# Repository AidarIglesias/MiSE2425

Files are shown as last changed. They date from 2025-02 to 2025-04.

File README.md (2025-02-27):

# MiSE2425
This repository is intended to work as a tracking tool for the project in the subject of Microcontollers and Embedded Systems at the University of Barcelona.

The project comprises of four main stages, listed as follows:

1. Resource Planning
2. Hardware Design
    1. Schematic Drawing
        1. Component distribution
        2. Wiring
        3. Labeling
        4. Annotating
        5. ERC Check
    2. PCB Layout
        1. Set design rules
        2. Import components from Schematic
        3. Placement
            1. Microcontroller
            2. RF sensitive components
            3. Power supply
            4. The rest
        4. Routing
            1. RF & High speed lines
            2. Differential pair lines
            3. Power lines
            4. The rest
        5. Copper pouring
    3. PCB Assembly & Soldering
3. Software Design
    1. Creating the workspace
    2. Importing libraries
    3. Creating sub-files
    4. Coding
    5. Building
    6. Test runs
    7. Optimizing the code
    8. Reparsing
    9. Decorating
4. Project Presentation

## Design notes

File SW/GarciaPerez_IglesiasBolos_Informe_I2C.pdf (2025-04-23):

# Desenvolupament del software del robot

## Enginyeria Electrònica de Telecomunicació Microcontroladors i Sistemes Empotrats Curs 2024/2025

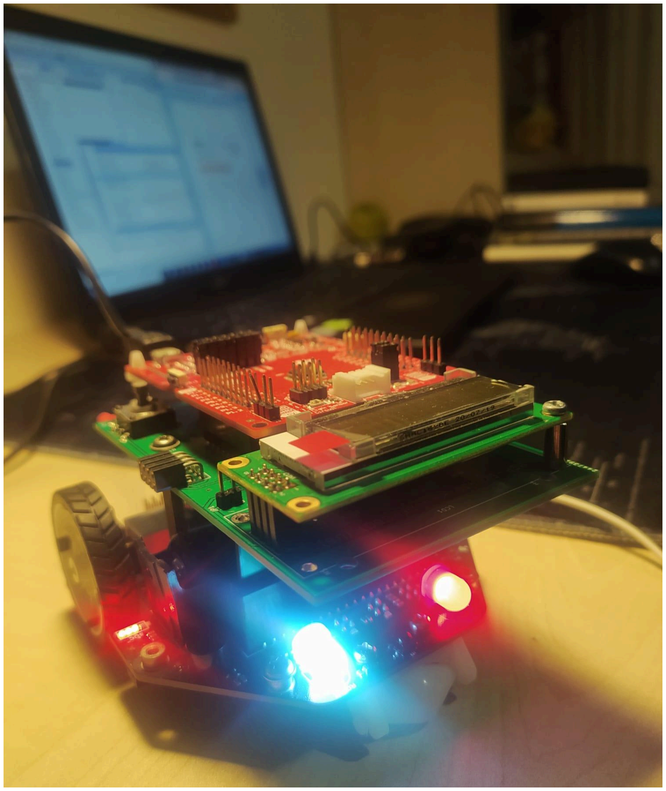
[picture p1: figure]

Aidar Iglesias | David García

Grau d'Enginyeria Electrònica de Telecomunicacions Microcontroladors i Sistemes Empotrats Curs 2024-2025
Informe desenvolupament del software del robot | Aidar Iglesias/David García Pérez

## ÍNDEX

Curs 2024-2025
Informe desenvolupament del software del robot | Aidar Iglesias/David García Pérez

## MOTIVACIÓ I OBJECTIUS

En aquest projecte, s’ha implementat un conjunt de funcionalitats a fi de controlar diferents perifèrics com LEDs RGB, motors, una pantalla LCD i un seguidor de línia, tots interconnectats mitjançant el protocol de comunicació I2C. L’objectiu principal ha estat programar aquest sistema per tal que pugui executar tasques senzilles, mitjançant interrupcions, temporitzadors i rutines d'espera.

Els diferents objectius particulars d’aquest informe son:

- Desenvolupar el software de manera escalada, mitjançant diferents fitxers C i generar els fitxers de capçalera.
- Crear una funció d’espera per controlar els retards que es troben dins del codi.
- Controlar diferents perifèrics mitjançant I2C. Entre ells, controlar els LEDs del robot, els actuadors de les rodes, la pantalla LCD i el seguidor de línia

## ESTRUCTURA GENERAL DEL SOFTWARE

El software del projecte s'organitza de manera modular per facilitar la llegibilitat, la reutilització i el manteniment del codi. Cada funcionalitat del robot relacionada amb la comunicació I2C o amb l’ús dels perifèrics digitals del microcontrolador es desenvolupa en fitxers de tipus C independents, acompanyats dels seus corresponents fitxers de capçalera, que defineixen les funcions globals accessibles des del programa main.

Aquesta modalitat permet encapsular les funcionalitats específiques com el control dels LEDs RGB, la gestió dels motors, la comunicació amb el display LCD o la configuració de rellotges i temporitzadors de manera individual.

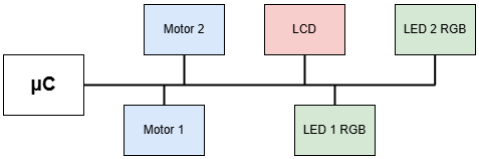
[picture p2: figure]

Figura 1: Visualització de diagrama I2C amb els diferents perifèrics.

Curs 2024-2025
Informe desenvolupament del software del robot | Aidar Iglesias/David García Pérez

## RECURSOS DE HARDWARE

Els models comercials que s’implementaran, juntament amb els seus corresponents Datasheets, es presenten a la Taula 1. A la Taula 2, es proporciona una breu descripció de cadascun.

Bloc | Recurs comercial | datasheet
Microcontrolador | MSP430FR2355TPT | MSP430FR2355TPT (https://www.ti.com/lit/ds/symlink/msp430fr2355.pdf?ts=1742411933840)
Robot | DFRobot Mcqueen Plus | DFRobot Mcqueen Plus (https://dfimg.dfrobot.com/nobody/wiki/9452afa67059f576c85b345bd385a060.pdf)
LCD | MD21605B6W-FPTLW3 | MD21605B6W-FPTLW3 (https://docs.rs-online.com/4d70/A700000009250608.pdf)
Ultrasons | URM10 | SEN0307 URM09 (https://wiki.dfrobot.com/URM09_Ultrasonic_Sensor_(Gravity_Analog)_SKU_SEN0307)
Oscil·lador | LFXTAL002997BULK | LFXTAL002997BULK (https://www.mouser.es/datasheet/2/741/LFXTAL002997Bulk-940265.pdf)
Joystick | THB001P | THB001P (https://www.ckswitches.com/media/2873/thb.pdf)
LDRs | NSL-19M51 | NSL-19M51 (https://eu.mouser.com/datasheet/2/1418/DS_NSL_19M51-2935293.pdf)
Mòdul wifi | ESP01 | ESP01 (https://docs.ai-thinker.com/_media/esp8266/docs/esp-01_product_specification_en.pdf)
Lògica joystick | LMV324 | LMV324 (https://www.ti.com/lit/ds/symlink/lmv324.pdf?ts=1742439205418)

Taula 1: Visualització dels recursos amb els respectius datasheets.

Recurs comercial | Característiques
MSP430FR2355TPT | Baix consum, memòria FRAM ràpida i múltiples protocols de comunicació
DFRobot Mcqueen Plus | Robot amb múltiples motors, sensors i funcionalitats.
MD21605B6W-FPTLW3 | Interfaç I2C senzilla, baix consum, més econòmic que una pantalla LED.
URM10 | Sensor d’alta precisió, però és més car que altres mòduls d’ultrasons.
LFXTAL002997BULK | Bona estabilitat, però requereix condensadors de càrrega per funcionar correctament.
THB001P | Joystick analògic amb un control precís dels dos eixos i un polsador integrat.
NSL-19M51 | Té una resposta no lineal que depèn molt de la il·luminació ambiental.
ESP01 | Aquest model concret de mòdul wifi té un baix cost, ocupa poca àrea i és programable amb altres entorns com arduino.
LMV324 | Operacional LM324 amb baix consum.

Taula 2: Visualització dels recursos amb una descripció.

Curs 2024-2025
Informe desenvolupament del software del robot | Aidar Iglesias/David García Pérez

## TAULA AMB PINS DEL µC

Per poder desenvolupar el software i saber quins pins s’han d’inicialitzar com a GPIOs així com tenir una idea de quins pins s’associen a cada funció del robot, s’ha adjuntat la taula amb les connexions del microcontrolador, indicant el nom del pin, el mòdul que es connecta a aquests pins i una petita descripció de la seva funció, especificant si es tracta d’una entrada o una sortida digital, una línia de comunicació (I2C, UART), una entrada analògica o un senyal específic.

Pin µC | Etiqueta | Component | Port/Pin amb funcionalitats | Descripció
2 ACLK | TP | Conn pinheader | P1.1/UCB0CLK/ACLK/OA0O/COMP0.1/A1 | Output. Test point del ACLK
3 SMCLK | TP | Conn_pinheader | P1.0/UCB0STE/SMCLK/COMP0.0/A0/Veref+ | Output. Test point del SMCLK
4 SBW | TCK | Spy By Wide | TEST/SBWTCK | I/O Pin de dades del SPW
5 SBW | TDIO | Spy By Wide | RST/NMI/SBWTDIO | I/O Pin de rellotge del Spy By Wire
6 | VCC | VCC | DVCC | Alimentació VCC
7 | GND | GND | DVSS | Gnd, punt de referència
8 XT1 | IN | CRISTALL | P2.7/TB0CLK/XIN | Input. Pin 1 del cristall
9 XT1 | OUT | CRISTALL | P2.6/MCLK/XOUT | Input. Pin 2 del cristall
12 I2C | SCL | LCD | P4.7/UCB1SOMI/UCB1SCL | SCL del I2C para conn.robot y LCD
13 I2C | SDA | LCD | P4.6/UCB1SIMO/UCB1SDA | SDA del I2C para conn. robot y LCD
14 RST | LCD | LCD | P4.5/UCB1CLK | Reset del LCD
20 | P0 | CONN_ROBOT | P6.2/TB3.3 | I/O. Pin digital per connexió robot
21 | P1 | CONN_ROBOT | P6.1/TB3.2 | I/O Pin digital per connexió robot
22 | P2 | CONN_ROBOT | P6.0/TB3.1 | I/O Pin digital per connexió robot
27 | P8 | CONN_ROBOT | P2.3/TB1TRG | I/O Pin digital per connexió robot
31 RX | ESP | MÒDUL WIFI | P1.7/UCA0TXD/UCA0SIMO/TB0.2/TDO/OA1 +/A7/VREF+ | Input. Connexió de recepció del mòdul wifi tipus UART.
32 TX | ESP | MÒDUL WIFI | P1.6/UCA0RXD/UCA0SOMI/TB0.1/TDI/TCL K/OA1-/A6 | Output. Connexió transmissió del mòdul wifi tipus UART.
37 JTK | R | joystick | P3.5/OA3O | Output. Pin digital del port 3 del joystick que determina direcció dreta (right).
38 JTK | F | joystick | P3.4/SMCLK | Output. Pin digital del port 3 del joystick que determina direcció endavant (forward)
42 LDR | R | LDR | P5.1/TB2.2/MFM.TX/A9 | Pin analògic del port 5 per LDR dret (right)
43 LDR | L | LDR | P5.0/TB2.1/MFM.RX/A8 | Pin analògic del port 5 per LDR esquerra (left)
44 JTK | SEL | joystick | P3.3/OA2+ | Ouput. Pin digital del pulsador del joystick per seleccionar al LCD.
45 JTK | B | joystick | P3.2/OA2- | Output. Pin digital del port 3 del joystick que determina direcció abaix (backward).
46 JTK | L | joystick | P3.1/OA2O | Output. Pin digital del port 3 del joystick que determina direcció esquerra (left).

Taula 3: Taula amb els diversos components de la placa i els pins corresponents del microcontrolador.

Curs 2024-2025
Informe desenvolupament del software del robot | Aidar Iglesias/David García Pérez

## DESCRIPCIÓ DE FUNCIONS DEL ROBOT

Com anteriorment s’ha esmentat, el robot integra diferents funcionalitats, proporcionades pels diferents perifèrics. Aquestes són controlades per una placa de desenvolupament MSP-EXP430FR2355, la qual té com a microcontrolador principal el MSP430FR2355 de Texas Instruments.

El desenvolupament de l’entorn de software del robot inclou funcions per al control de temporitzadors mitjançant l’ús de rellotges i funcions per al control de perifèrics, tals com LEDs RGB, actuadors i un display LCD.

El control dels LEDs RGB es realitza via protocol de comunicació I2C. S’han definit funcions per al control de l’encesa i l’apagada dels esmentats, així com per al color.

A més, el robot també té la capacitat de desplaçar-se en totes les direccions del pla sobre el qual reposa gràcies a un conjunt de dos actuadors programables per usuari. Per a aquest perifèric s’han desenvolupat un seguit de funcions que permeten el control del moviment del robot en diverses direccions. La comunicació entre la placa i el controlador dels actuadors també es fa a través d’I2C.

Addicionalment, el robot està dotat d’una petita pantalla de tipus LCD de dues línies de 16 caràcters per línia, també controlada mitjançant el protocol I2C. En el projecte s’ha creat funcions per a la representació de caràcters a través de la pantalla LCD.

Per la mateixa naturalesa del protocol de comunicació, per a cadascun dels mòduls de software que implementen el control de cadascun dels perifèrics s’ha establert un format de trama específic que inclou l’adreça del perifèric a controlar, el conjunt de dades a enviar i la longitud de la trama.

Cal destacar que totes les funcions esmentades anteriorment tenen la seva contrapart d’inicialització, que és necessària per al correcte funcionament dels perifèrics del nostre robot i, en general, per a qualsevol sistema encastat.

Curs 2024-2025
Informe desenvolupament del software del robot | Aidar Iglesias/David García Pérez

## Rellotges

En aquest projecte s’han utilitzat dues fonts de rellotge: una de 16 MHz proporcionada pel DCO (Digitally Controlled Oscillator) i una altra de 32 kHz generada pel cristall extern XT1. A través dels pins de sortida configurats al LaunchPad, s’han pogut visualitzar amb l’oscil·loscopi els dos senyals corresponents. A les Figures 2 i 3, respectivament, s’observa clarament que el senyal de 16 MHz presenta una forma d’ona més distorsionada en comparació amb la de 32 kHz. Aquesta distorsió és causada per diversos factors, com ara el soroll introduït per l’elevada freqüència, la capacitat paràsita del circuit, o limitacions de la instrumentació utilitzada. En canvi, el senyal de 32 kHz es mostra molt més estable i net, ja que treballa a una freqüència inferior i prové d’un oscil·lador més estable com és el cristall.

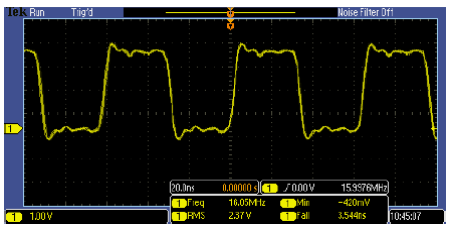
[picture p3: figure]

Figura 2: Visualització de la font de rellotge de 16 MHz.

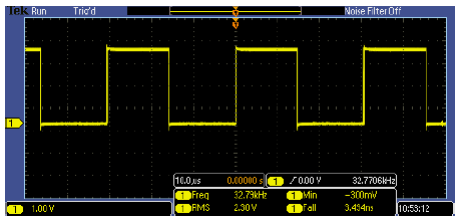
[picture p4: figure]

Figura 3: Visualització de la font de rellotge de 32 kHz.

Curs 2024-2025
Informe desenvolupament del software del robot | Aidar Iglesias/David García Pérez

### Funció delay_ms()

Per implementar retards precisos al sistema, s’ha desenvolupat la funció | delay_ms(), que permet
generar una espera en mil·lisegons. Aquesta funció inicialitza un comptador global | count_ms | i
utilitza el Timer B3 del microcontrolador per incrementar aquest valor mitjançant una interrupció generada cada 1 ms. Quan es crida la funció, s'entra en un bucle d’espera que no finalitza fins que el comptador arriba al valor indicat. L'increment del comptador es produeix a través de la subrutina d’interrupció TimerB0_ISR(). A la Figura 4 es pot observar el diagrama de flux corresponent al funcionament de la funció delay_ms(). A la Figura 5 es pot visualitzar el pols generat per un GPIO configurat com a sortida amb període de 200 ms (retard de 100 ms entre commutacions).

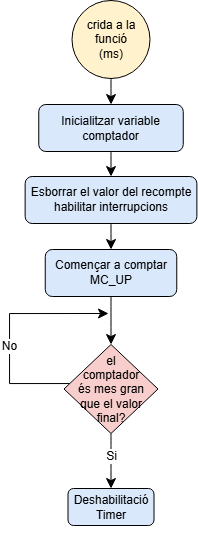
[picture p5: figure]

Figura 4: Diagrama de flux de la funció delay.

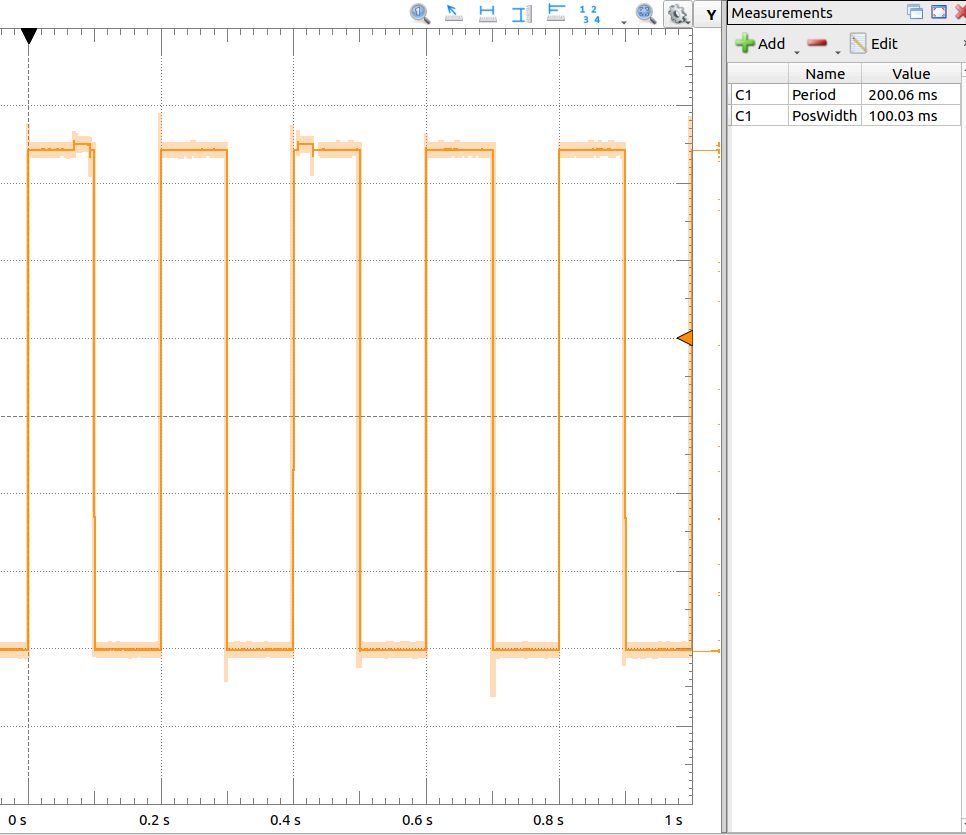
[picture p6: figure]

Figura 5: Visualització del retard generat per la funció delay amb l’oscil·loscopi. S’aprecia a la finestra de mesures que el període d’espera és de 100 ms.

## Timers

Per tal de generar temporitzacions precises en el sistema, s'ha utilitzat el mòdul TimerB3 del microcontrolador. A la funció init_TimerB(), es configura aquest temporitzador amb el rellotge SMCLK com a font, funcionant a 16 MHz. S'estableix un valor de recompte de 16000 cicles, que equival a un període d’1 mil·lisegon (tenint en compte que 1 cicle = 1/16 MHz). Aquest temporitzador s’utilitza principalment com a base per a la funció delay_ms(), la qual permet generar retards amb precisió en mil·lisegons.

Curs 2024-2025
Informe desenvolupament del software del robot | Aidar Iglesias/David García Pérez

## LEDs RGB

Els LEDs frontals del robot es controlen mitjançant trames enviades a través de l’I2C. Cada trama enviada consta de tres bytes: una adreça funcional que identifica el mòdul LED, i dos valors corresponents als colors dels LEDs esquerre i dret. A la Taula 4 es visualitza la trama enviada al robot i a la Figura 6 es veu el resultat obtingut a l’analitzador de protocols de l’Analog Discovery 2. Aquest sistema permet encendre els LEDs en diferents combinacions de color. Cada color es codifica amb un número de l’1 al 7, on cada valor representa un color específic com vermell, verd, blau, etc. A la Taula 5 es recopilen els diferents colors possibles. A la Figura 7 es presenta un exemple d’aplicació de la funció.

Adreça Robot | Adreça LED | Color1 | Color2 | Mida de la trama
0x10 | 0x0B | color LED esq. | color LED dret | 3
Taula 4: Taula amb la trama que s’envia al robot.
Color | Identificador
Vermell | 1
Verd | 2
Groc | 3
Blau | 4
Magenta | 5
Cyan | 6
Blanc | 7
Taula 5: Taula amb els colors disponibles i els seus identificadors.

Figura 6: Visualització de la trama I2C dels LEDs amb ajut de l’analitzador de protocols de l’Analog Discovery 2.

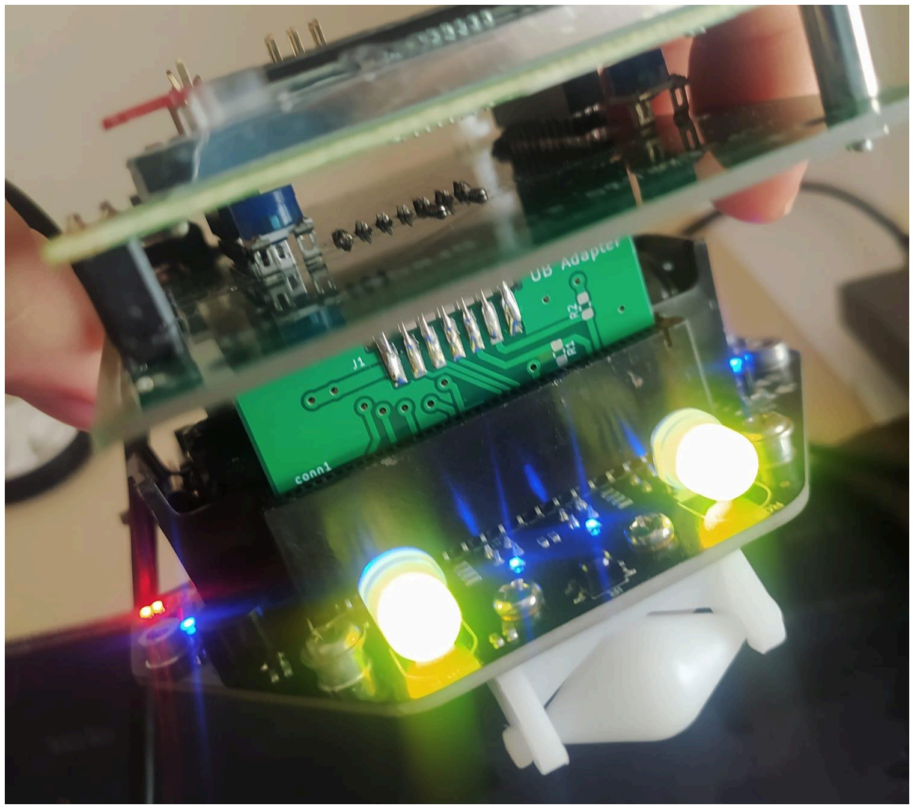
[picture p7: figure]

Figura 7: Visualització dels LEDs de color groc al robot.

Curs 2024-2025
Informe desenvolupament del software del robot | Aidar Iglesias/David García Pérez

## Motors/Actuadors

Els motors del robot es controlen també mitjançant comunicació I2C enviant trames més llargues, de cinc bytes. Aquesta trama que es visualitza a la Taula 7, conté una adreça del mòdul motor, la direcció i la velocitat de cada motor (esquerre i dret). La direcció pot ser endavant o enrere, i la velocitat s’expressa amb un valor entre 0 i 255.

Per facilitar el control, s’han implementat funcions que encapsulen aquestes trames. A la Taula 6 es recopilen les esmentades, junt amb una petita descripció.

Funció | Descripció
move_forward(uint8_t fvel) | Ambdós motors actuen en la direcció posterior.
move_backward(uint8_t bvel) | Ambdós motors actuen en la direcció anterior.
fleft(uint8_t fleft_vel) | Únicament el motor dret actua en la direcció posterior.
bleft(uint8_t bleft_vel) | Únicament el motor dret actua en la direcció anterior.
left_rot(uint8_t lrot_vel) | Ambdós motors actuen en direccions oposades (motor esquerre enrere, motor dret endavant).
fright(uint8_t fright_vel) | Únicament el motor esquerre actua en la direcció posterior.
bright(uint8_t bright_vel) | Únicament el motor esquerre actua en la direcció anterior.
right_rot(uint8_t rrot_vel) | Ambdós motors actuen en direccions oposades (motor esquerre endavant, motor dret enrere).
stop(void) | Deshabilitar ambdós motors (posar la velocitat dels dos a zero).

Taula 6: Taula amb les funcions desenvolupades pels actuadors amb una descripció

ID_robot | Adreça controlador motors | Moviment motor esquerre 1 | velocitat motor esquerre | Moviment motor dret ¹ | velocitat motor dret | Mida de la trama
0x10 | 0x00 | 1 o 2 | 0-255 | 1 o 2 | 0-255 | 5
Taula 7: Visualització de la trama que s’envia als motors.

A la Figura 8 s’aprecia l’enviament d'instruccions als actuadors via I2C, mitjançant l’analitzador de protocols de l’Analog Discovery 2. Es pot veure que les dades enviades segueixen el mateix ordre que l’especificat a la Taula 7 anteriorment: identificador del robot, adreça del controlador de motors, direcció de moviment del motor esquerre, velocitat del motor esquerre, direcció del motor dret i velocitat del motor dret.

1 La direcció del moviment està definida com: direcció posterior = 1, direcció anterior = 2.

Curs 2024-2025
Informe desenvolupament del software del robot | Aidar Iglesias/David García Pérez

Figura 8: Visualització de la trama dels motors amb l’Analog Discovery 2. (1ª línia: comanda de moure endavant, 2ª línia: comanda d’aturar els motors)

Tanmateix, a les Figures 9 i 10 es mostren el diagrama de flux del funcionament general de les funcions que componen el mòdul dels actuadors i un exemple d’implementació en software d’una de les funcions de control dels motors, respectivament.

void move_forward(uint8_t fvel){ actuator_buf[0] =
LOC_ACTUATOR_ADDR;
actuator_buf[1] = FDIR;
actuator_buf[2] = fvel;
actuator_buf[3] = FDIR;
actuator_buf[4] = fvel;
I2C_send(LOC_ID_ROBOT,
actuator_buf, actuator_blen); }

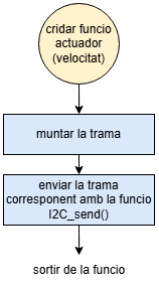
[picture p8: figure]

Figura 9: Visualització del diagrama de flux que segueixen les funcions

Figura 10: Implementació en software de la funció per moure el robot endavant (vegeu Taula 6).

2

2 Tant els diferents camps del búffer de dades de la trama actuator_buf[] com els arguments de la funció mare i la instrucció I2C_send() estan prèviament definits/inicialitzats.

Curs 2024-2025
Informe desenvolupament del software del robot | Aidar Iglesias/David García Pérez

## LCD Display

Per controlar el display LCD s’implementen missatges codificats en ASCII. Per fer-ho, s'utilitza un búffer on s'emmagatzema el text mitjançant la funció sprintf(), que converteix la cadena de text en caràcters ASCII. El primer byte del buffer és sempre 0x40 ⇒ @, indicant que el que segueix són dades a mostrar. Un cop preparat, el missatge es transmet a través de la funció I2C_send(). Quan aquesta transmissió es realitza, és possible observar les trames corresponents de les línies SCL i SDA amb l’oscil·loscopi, mostrant els impulsos de rellotge i les dades del text enviat bit a bit. A la Figura 8 es mostra una trama genèrica per a enviar missatges al display LCD via el protocol I2C.

Adreça LCD | Búffer amb els caràcters del missatge | Mida del búffer
0x3E | Array de tipus uint8_t | Depèn del missatge
Taula 8: Visualització de la trama que s’envia a l’LCD.

D’altra banda, existeixen també un cert seguit de funcions útils per al control de la pantalla LCD. Aquestes funcions es detallen a la Figura 11 amb els corresponents diagrames de flux.

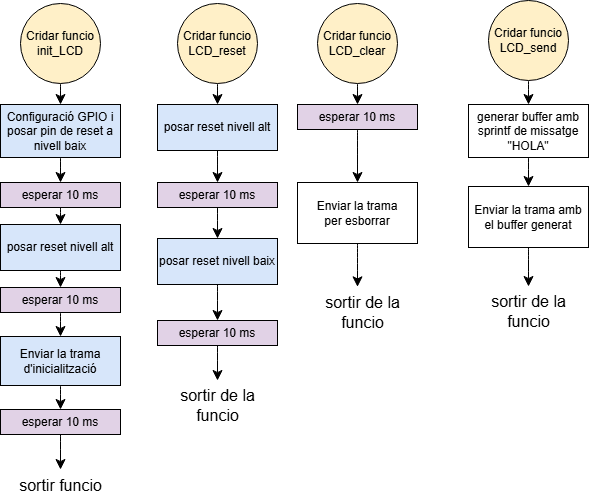
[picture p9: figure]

Figura 11: Diagrames de flux de les diferents funcions per controlar l’LCD.

3

3 La trama d’inicialització es compon dels caràcters 0x00, 0x39, 0x14, 0x74, 0x54, 0x6F, 0x0C i 0x01.

Curs 2024-2025
Informe desenvolupament del software del robot | Aidar Iglesias/David García Pérez

A la Figura 12 s’analitza la trama d’enviament de dades al display LCD via I2C mitjançant l’analitzador de protocols. A les Figures 13 i 14 es presenten una imatge de la visualització física de contingut a la pantalla i la implementació d’una de les funcions de control del display, respectivament.

Figura 12: Visualització de trama I2C via AD2.
(1ª línia: inicialització de l’LCD, 2ª línia: missatge «Hello World»)

void LCD_send(){
llarg = sprintf(cadena,"@INFORME ",llarg); I2C_send(0x3E,cadena,llarg);

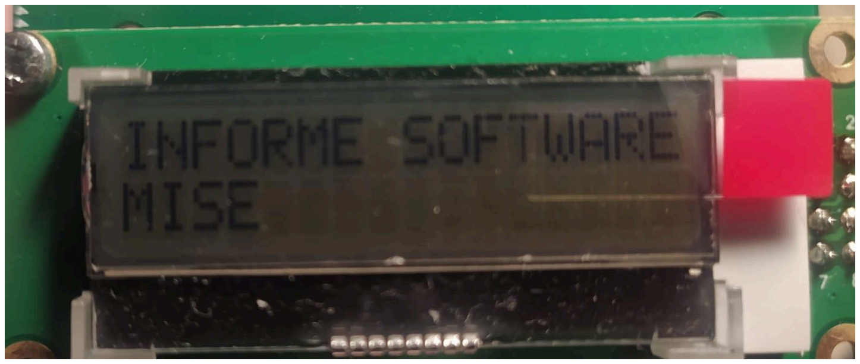
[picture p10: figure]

llarg = sprintf(cadena,"@SOFTWARE ",llarg); I2C_send(0x3E,cadena,llarg);

uint8_t cursor_segona_linea[2] = {0x00, 0xC0};
I2C_send(0x3E, cursor_segona_linea, 2); delay_ms(10);

llarg = sprintf(cadena, "@MISE"); I2C_send(0x3E, (uint8_t*)cadena, llarg); }
Figura 13: Imatge amb text escrit a l’LCD. | Figura 14: Implementació en software de la funció per a l’enviament de dades a la pantalla LCD.

Curs 2024-2025
Informe desenvolupament del software del robot | Aidar Iglesias/David García Pérez

## Line-Tracking

El mòdul Line-Tracking o seguiment de línia permet al robot detectar canvis d'intensitat lluminosa gràcies a uns fotodetectors instal·lats a la part inferior de la placa base del robot. Aquests, en detectar un canvi d’intensitat (per exemple, al passar d’una superfície clara a una superfície fosca) envien un nombre binari de 6 bits que representen quins fotodetectors han detectat un canvi de luminància. Aquests conformen els 6 bits de menor pes del registre d’estat dels fotodetectors. La Taula 9 mostra el registre d’estat dels fotodetectors.

a7 | a6 | a5 | a4 | a3 | a2 | a1 | a0
x | x | r | r | r | r | r | r
Taula 9: Registre d’estat dels fotodetectors. Únicament de lectura. Útils són els 6 bits de menor pes.

El diagrama de flux de la funció es mostra a la Figura 16 i a la Figura 15 es mostra el robot seguint la línia.

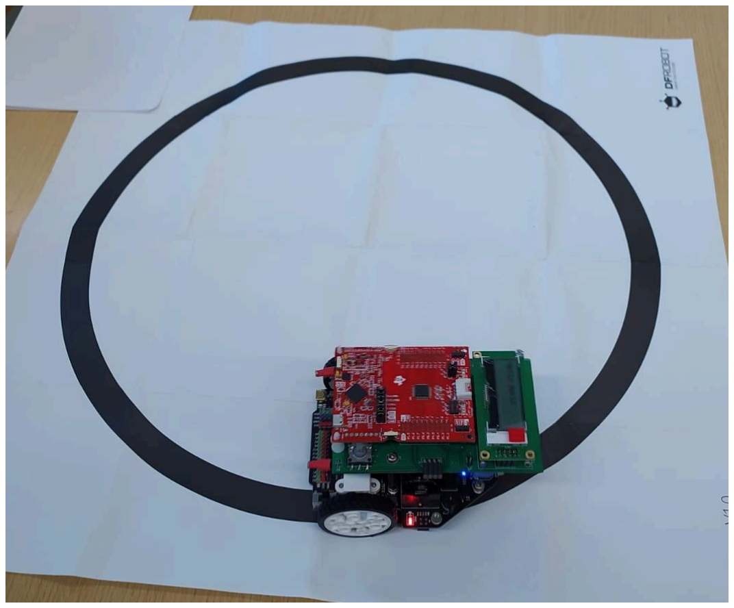
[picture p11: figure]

Figura 15: Visualització del robot funcionant amb el linetracking

Curs 2024-2025
Informe desenvolupament del software del robot | Aidar Iglesias/David García Pérez

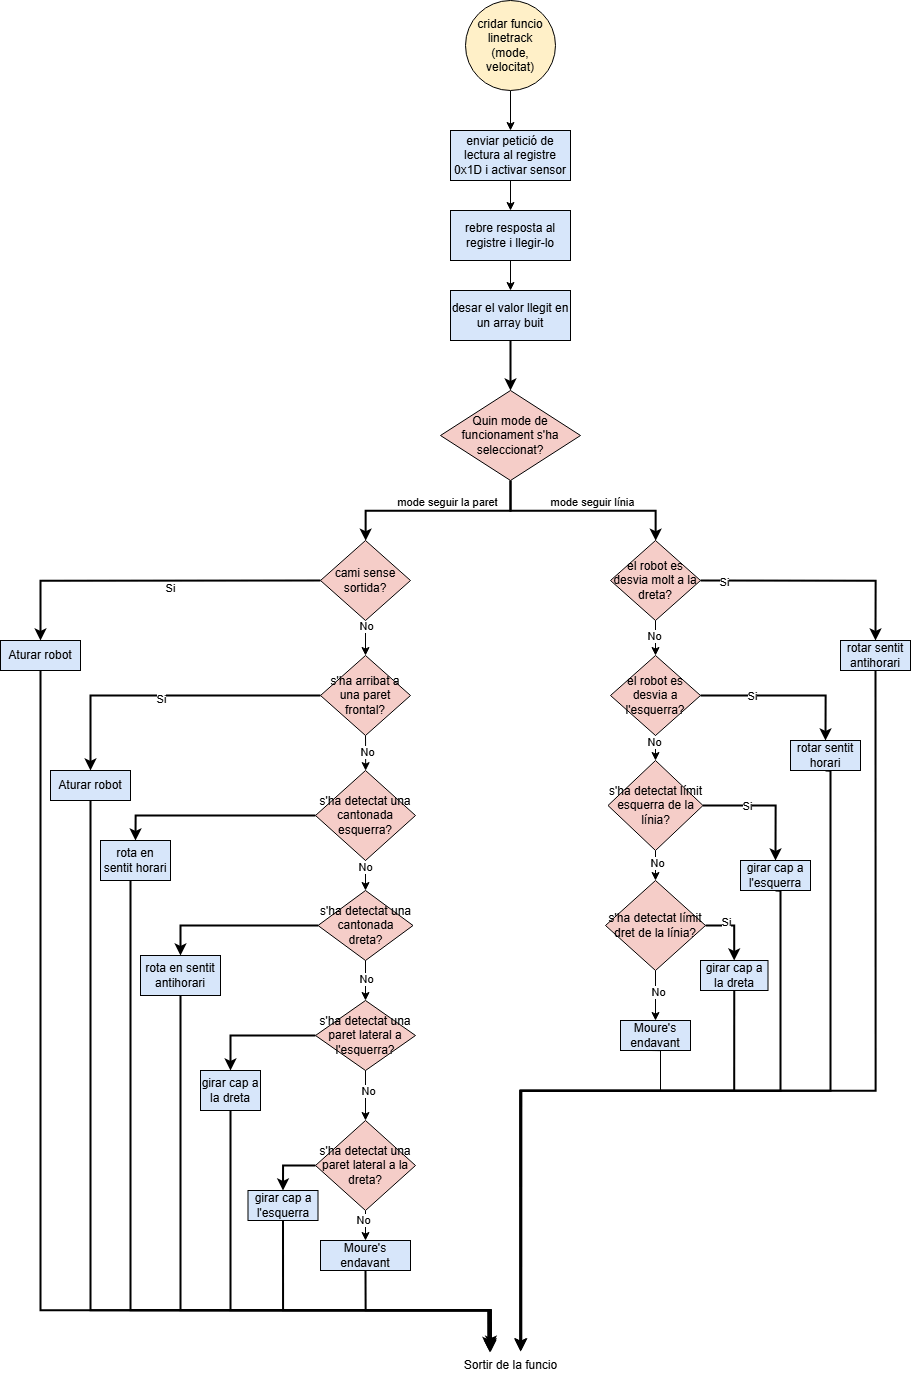
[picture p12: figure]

Figura 16: Diagrama de flux de la funció linetracking()

Curs 2024-2025
Informe desenvolupament del software del robot | Aidar Iglesias/David García Pérez

## CONCLUSIONS

En aquest informe s'ha explicat el funcionament del codi de control implementat en el robot dissenyat anteriorment. Integra múltiples perifèrics que venien inclosos al DFRobot Mcqueen Plus V2 i recursos externs a través del bus I2C. El desenvolupament del software ha permès entendre el funcionament del BUS I2C a escala de capa d’enllaç, generant trames definides per usuari amb l’adreça de l’esclau, la direcció de comunicació (escriptura o lectura), les dades i bits de confirmació (NACK i ACK).

S’ha pogut comprovar l’ús del bus I2C per controlar dispositius externs amb trames específiques, i s’ha verificat que la resposta del sistema és correcte i coherent amb l’oscil·loscopi i l’AD2. Sempre que es tinguin en compte aspectes crítics com la sincronització i les esperes necessàries després de cada transmissió.

El projecte ha servit per aplicar els coneixements teòrics de programació en llenguatge C per a la placa dissenyada amb anterioritat. Finalment, l’estructura en blocs del codi afavoreix l'escalabilitat del projecte, cosa que permet afegir noves funcionalitats de manera senzilla.

Curs 2024-2025
Informe desenvolupament del software del robot | Aidar Iglesias/David García Pérez

## ANNEXOS

## DELAY

/*
* delay_ms.c
*
* Microcontroladors i Sistemes Empotrats * Curs 2024-25
* Universitat de Barcelona
*
* Autors: David Garcia, Aidar Iglesias */

/******************************* LLIBRERIES *************************************/ #include <msp430fr2355.h>
#include <stdint.h>

#include "timers.h"

/*********************************************************************** *********/

/************************** Variables de control ********************************/
uint16_t count_ms = 0;
/*********************************************************************** *********/

/**************************** Funció delay_ms ***********************************/
/* La funcio delay_ms accepta un unic argument de tipus enter de 8 bits i no retorna
* cap dada (tipus void). L'argument que se li passa a la funcio es la quantitat de
* temps d'espera (en mil·lisegons) que es desitja fer.
*
* La funcio explota el Timer B3 com a temporitzador per al recompte del pas del temps.
* A l'inici es fa la inicialitzacio del temporitzador: s'esborra el valor emmagat-

Curs 2024-2025
Informe desenvolupament del software del robot | Aidar Iglesias/David García Pérez

* zemat al registre de recompte, s'habiliten les interrupcions de comptador i s'ha-
* bilita el temporitzador. Un cop acabat el recompte, es deshabilita el temporitzador.
*
* El recompte es controla mitjançant una variable de recompte que s'incrementa mitjan-
* çant una interrupcio, la qual es genera cada cop que el temporitzador finalitza el
* periode d'un mil·lisegon.
*/
void delay_ms(uint16_t ms){ // Funció d'espera de milisegons
count_ms = 0; | // Inicialitzem la variable
count_ms a 0
TB3CTL |= TBCLR; | // Esborrem el valor de recompte
TB3CCTL0 |= CCIE; | // Habilitem les interrupcions
del comptador del TimerB3
TB3CTL |= MC__UP; | // Comencem el recompte
while(count_ms < ms){
// cos del bucle buit (comptant...)
}
TB3CTL &= ~(MC__UP); | // Deshabilitem el TimerB3
}
/*********************************************************************** *********/

/*********************** Inicialització ISR del TimerB3 *************************/
#pragma vector = TIMER3_B0_VECTOR

__interrupt void TimerB0_ISR (void){
count_ms += 1; // Incrementem la variable de recompte en 1 i deshabilitem les interrupcions.
}
/*********************************************************************** *********/

Curs 2024-2025
Informe desenvolupament del software del robot | Aidar Iglesias/David García Pérez

## LCD

/*
* LCD_display.c
*
* Microcontroladors i Sistemes Empotrats * Curs 2024-25
* Universitat de Barcelona
*
* Autors: David Garcia, Aidar Iglesias */

/********************************* LLIBRERIES ***************************************/ #include <msp430fr2355.h>
#include <stdint.h>

#include <stdio.h>

#include "i2c_master.h"

#include "delay_ms.h"

/*********************************************************************** *************/

/**************************** Variables de control **********************************/
#define LOC_ID_ROBOT 0x10 // Variable local de l'identificador del robot

#define WAIT_10MS 10 | // Variable de delay d'inicialització (10ms)

#define LOC_LCD_ADDR 0x3E // Variable local adreça del LCD

uint8_t LCD_init_buf[8] = {0x00, 0x39, 0x14, 0x74, 0x54, 0x6F, 0x0C, 0x01}; // Búffer d'inicialització del LCD
const uint8_t LCD_init_blen = sizeof(LCD_init_buf); // Longitud del búffer d'inicialització
uint8_t LCD_clear_buf[2] = {0x00, 0x01}; | // Búffer per a
esborrar el contingut en pantalla
const uint8_t LCD_clear_blen = sizeof(LCD_clear_buf); // Longitud del búffer d'esborrar contingut en pantalla
uint8_t LCD_cursor_reset_buf[2] = {0x00, 0x03}; | // Búffer per a
posicionar el cursor a l'inici de línia
const uint8_t LCD_cursor_reset_blen = sizeof(LCD_cursor_reset_buf); // Longitud del búffer per a posicionar el cursor a l'inici de línia /***********************************************************************

Curs 2024-2025
Informe desenvolupament del software del robot | Aidar Iglesias/David García Pérez

*************/

/******************* Funció d'inicialització del display LCD ************************/
/* La funcio 'init_LCD' s'encarrega d'inicialitzar els parametres del display LCD
* d'acord amb les seves caracteristiques fisiques (2x16 caracters) i electriques
* (3.3V d'alimentacio).
*
* En concret, s'habilita el senyal de reset de la pantalla LCD (GPIO del microcon-
* trolador) durant un cert temps especificat pel fabricant i despres de deshabili-
* tar-lo, s'envia una seqüencia de caracters per I2C que el configuren. */
void init_LCD(void){
P5DIR |= BIT2; | // Configurem el pin GPIO del reset del LCD
com a sortida (actiu per nivell baix
P5OUT &= ~(BIT2); | // Posem el pin de reset a nivell lògic baix
(habilitem reset)
delay_ms(WAIT_10MS); // Esperem un temps de configuració (requeriment del fabricant)
P5OUT |= BIT2; | // Posem el pin de reset a nivell lògic alt
(deshabilitem reset)
delay_ms(WAIT_10MS); // Esperem un temps de configuració (requeriment del fabricant)
I2C_send(LOC_LCD_ADDR, LCD_init_buf, LCD_init_blen); // Enviem la trama d'inicialització per I2C
delay_ms(WAIT_10MS); // Esperem un temps de configuració (requeriment del fabricant)
}
/*********************************************************************** *************/

/************************* Funció de reset del display LCD **************************/
/* La funcio 'LCD_reset' envia un senyal de reset al display LCD. La utilitat de la
* funcio es desfer-se de la tasca de treballar a nivell de GPIOs. Amb nomes cridar

Curs 2024-2025
Informe desenvolupament del software del robot | Aidar Iglesias/David García Pérez

* la funcio ja es fa el reset.
*/
void LCD_reset(void){
P5OUT &= ~(BIT2); | // Habilitem reset
delay_ms(WAIT_10MS); | // Esperem 10ms
P5OUT |= BIT2; | // Deshabilitem reset
delay_ms(WAIT_10MS); | // Esperem 10ms
}
/*********************************************************************** *************/

/****************** Funció per esborrar el contingut del display LCD ****************/
/* La funcio 'LCD_clear' te com a finalitat esborrar el contingut presentat a la pan-
* talla. La posicio del cursor tambe retorna al primer caracter de la primera linia.
*/
void LCD_clear(void){
delay_ms(WAIT_10MS); // Esperem 10ms
I2C_send(LOC_LCD_ADDR, LCD_clear_buf, LCD_clear_blen); // Enviem comanda d'esborrament en
// pantalla per I2C
}
/*********************************************************************** *************/

/********** Funció per posar el cursor del display LCD a la posició inicial**********/
/* La funcio 'LCD_cursor_reset' s'empra per, en el moment que es desitgi, retornar el
* cursor a la posicio inicial, es a dir, al primer caracter de la primera linia.
*/
void LCD_cursor_reset(void){
delay_ms(WAIT_10MS); // Esperem 10ms
I2C_send(LOC_LCD_ADDR, LCD_cursor_reset_buf, LCD_cursor_reset_blen); // Enviem comanda de
// posicionament del cursor a l'inici de la primera línia del display
}

Curs 2024-2025
Informe desenvolupament del software del robot | Aidar Iglesias/David García Pérez

/*********************************************************************** *************/

/********** Funcio sprintf per posar missatge "INFORME SOFTWARE MISE" ***************/
/* La funcio 'LCD_send' envia la cadena "INFORME SOFTWARE MISE" a la pantalla LCD.
* Per fer-ho, es construeixen les diferents cadenes corresponents a cada paraula
* de la frase i s'envien via I2C al display.
*/
void LCD_send(void){
uint8_t cadena[10]; // Declarem un array per desar la cadena de caracters
uint8_t llarg; | // Declarem la mida de la cadena de caracters

/* Construim la cadena de caracters mitjançant la funcio 'sprintf' de la
* llibreria <stdio.h> de C
*/
llarg = sprintf(cadena,"@INFORME ",llarg);
I2C_send(LOC_LCD_ADDR, cadena, llarg); | // Enviem la cadena per
I2C al LCD

// Repetim el mateix per a la següent paraula
llarg = sprintf(cadena,"@SOFTWARE ",llarg);
I2C_send(LOC_LCD_ADDR, cadena, llarg); | // Enviem la cadena per
I2C al LCD

/* Enviem una cadena de caracters que corresponen a un salt de linia * (vegeu app. note del fabricant per a les trames de control)
*/
uint8_t cursor_segona_linea[2] = {0x00, 0xC0}; I2C_send(LOC_LCD_ADDR, cursor_segona_linea, 2); // Enviem la cadena per I2C al LCD
delay_ms(WAIT_10MS); | // Esperem 10ms

// Construim la cadena per a la ultima paraula de la frase
llarg = sprintf(cadena, "@MISE");
I2C_send(LOC_LCD_ADDR, (uint8_t*)cadena, llarg); // Enviem la cadena per I2C al LCD
}

Curs 2024-2025
Informe desenvolupament del software del robot | Aidar Iglesias/David García Pérez

/*********************************************************************** *************/

## LEDs

/*
* LEDs.c
*
* Microcontroladors i Sistemes Empotrats * Curs 2024-25
* Universitat de Barcelona
*
* Autors: David Garcia, Aidar Iglesias */

/********************************* LLIBRERIES ***************************************/ #include <msp430fr2355.h>
#include <stdint.h>

#include "timers.h"

#include "delay_ms.h"

#include "i2c_master.h"

/*********************************************************************** *************/

/**************************** Variables de control **********************************/
// LEDs RGB robot
// colors: 1-->RED, 2-->GREEN, 3-->YELLOW, 4-->BLUE, 5-->MAGENTA, 6-->CYAN, 7-->WHITE
#define OFF 0

#define RED 1

#define GREEN 2

#define YELLOW 3

#define BLUE 4

#define MAGENTA 5

#define CYAN 6

#define WHITE 7

// Paràmetres I2C dels LEDs
#define LOC_ID_ROBOT 0x10 | // Adreça del robot

#define LED_addr 0x0B | // Adreça del controlador dels LEDs RGB del

Curs 2024-2025
Informe desenvolupament del software del robot | Aidar Iglesias/David García Pérez

robot
#define LED_BLEN 3 | // Longitud del buffer de dades dels LEDs

// Trames per a cada funció (el funcionament no es limita a les presentades)
uint8_t LEDs_OFF_buffer[3] = {LED_addr, OFF, OFF};
uint8_t RED_LEDs_buffer[3] = {LED_addr, RED, RED};
uint8_t GREEN_LEDs_buffer[3] = {LED_addr, GREEN, GREEN}; uint8_t YELLOW_LEDs_buffer[3] = {LED_addr, YELLOW, YELLOW}; uint8_t BLUE_LEDs_buffer[3] = {LED_addr, BLUE, BLUE};
uint8_t MAGENTA_LEDs_buffer[3] = {LED_addr, MAGENTA, MAGENTA}; uint8_t CYAN_LEDs_buffer[3] = {LED_addr, CYAN, CYAN};
uint8_t WHITE_LEDs_buffer[3] = {LED_addr, WHITE, WHITE}; uint8_t CULE_LEDs_buffer[3] = {LED_addr, BLUE, RED};
uint8_t MERENGUE_LEDs_buffer[3] = {LED_addr, WHITE, WHITE};
uint8_t PERICO_LEDs_buffer[3] = {LED_addr, WHITE, BLUE};
uint8_t GIRONI_LEDs_buffer[3] = {LED_addr, RED, WHITE}; /*********************************************************************** *************/

/*********************** Funcions de control dels LEDs ******************************/
/* Funcions per a l'activació dels LEDs RGB del robot. Les funcions envien una coman-
* da I2C per encendre els LEDs desitjats amb el color especificat.
*
* Cal destacar que en aquesta llibreria es recullen unicament funcions que encenen
* ambdos LEDs RGB del robot del mateix color. En cas de desitjar una altra combinacio
* de colors, s'han de definir la trama i la funcio corresponents, les quals permeten
* aquest comportament. Alternativament, es pot fer l'enviament d'instruccions al cos
* del programa main.c directament.
*/
void reset_LEDs(void){ // Funció per a apagar els LEDs delay_ms(1);
I2C_send(LOC_ID_ROBOT, LEDs_OFF_buffer, LED_BLEN);
}

void red_LEDs(void){ // Funció per a encendre els LEDs de color vermell

Curs 2024-2025
Informe desenvolupament del software del robot | Aidar Iglesias/David García Pérez

delay_ms(1);
I2C_send(LOC_ID_ROBOT, RED_LEDs_buffer, LED_BLEN);
}

void green_LEDs(void){ // Funció per a encendre els LEDs de color verd delay_ms(1);
I2C_send(LOC_ID_ROBOT, GREEN_LEDs_buffer, LED_BLEN);
}

void yellow_LEDs(void){ // Funció per a encendre els LEDs de color groc delay_ms(1);
I2C_send(LOC_ID_ROBOT, YELLOW_LEDs_buffer, LED_BLEN);
}

void blue_LEDs(void){ // Funció per a encendre els LEDs de color blau delay_ms(1);
I2C_send(LOC_ID_ROBOT, BLUE_LEDs_buffer, LED_BLEN);
}

void magenta_LEDs(void){ // Funció per a encendre els LEDs de color magenta
delay_ms(1);
I2C_send(LOC_ID_ROBOT, MAGENTA_LEDs_buffer, LED_BLEN);
}

void cyan_LEDs(void){ // Funció per a encendre els LEDs de color cyan delay_ms(1);
I2C_send(LOC_ID_ROBOT, CYAN_LEDs_buffer, LED_BLEN);
}

void white_LEDs(void){ // Funció per a encendre els LEDs de color blanc delay_ms(1);
I2C_send(LOC_ID_ROBOT, WHITE_LEDs_buffer, LED_BLEN);
}

void cule_LEDs(void){ // Funció per a encendre els LEDs de color blaugrana
delay_ms(1);
I2C_send(LOC_ID_ROBOT, CULE_LEDs_buffer, LED_BLEN);
}

void merengue_LEDs(void){ // Funció per a encendre els LEDs de color merengue

Curs 2024-2025
Informe desenvolupament del software del robot | Aidar Iglesias/David García Pérez

delay_ms(1);
I2C_send(LOC_ID_ROBOT, MERENGUE_LEDs_buffer, LED_BLEN);
}

void perico_LEDs(void){ // Funció per a encendre els LEDs de color blanc
delay_ms(1);
I2C_send(LOC_ID_ROBOT, PERICO_LEDs_buffer, LED_BLEN);
}

void gironi_LEDs(void){ // Funció per a encendre els LEDs de color gironi
delay_ms(1);
I2C_send(LOC_ID_ROBOT, GIRONI_LEDs_buffer, LED_BLEN);
}
/*********************************************************************** *************/

Curs 2024-2025
Informe desenvolupament del software del robot | Aidar Iglesias/David García Pérez

## ACTUADORS

/*
* actuadors.c
*
* Microcontroladors i Sistemes Empotrats * Curs 2024-25
* Universitat de Barcelona
*
* Autors: David Garcia, Aidar Iglesias
*/

/***************************** MACROS I LLIBRERIES **********************************/
#include <msp430fr2355.h>

#include <stdint.h>

#include "i2c_master.h"

/*********************************************************************** *************/

/***************************** Variables de control *********************************/
#define LOC_ID_ROBOT 0x10 | // Identificador local del robot (a

nivell de llibreria)
#define LOC_ACTUATOR_ADDR 0x00 // Adreça local dels actuadors (a nivell de llibreria)

#define FDIR 1 | // Direcció de moviment posterior

#define BDIR 2 | // Direcció de moviment anterior

#define STOP_WHEEL 0 | // Variable que defineix l'estat de

rodes aturades
uint8_t actuator_buf[5]; | // Búffer que emmagatzema l'estat dels
actuadors
uint8_t actuator_blen = sizeof(actuator_buf); // Longitud del búffer d'estat dels actuadors
/*********************************************************************** *************/

/************************* Funcions per al moviment del robot ***********************/
// Funció per a aturar el robot
void stop(void){

Curs 2024-2025
Informe desenvolupament del software del robot | Aidar Iglesias/David García Pérez

actuator_buf[0] = LOC_ACTUATOR_ADDR;
actuator_buf[1] = FDIR;
actuator_buf[2] = STOP_WHEEL;
actuator_buf[3] = FDIR;
actuator_buf[4] = STOP_WHEEL; I2C_send(LOC_ID_ROBOT, actuator_buf, actuator_blen); }

// Funció per a moure endavant el robot
void move_forward(uint8_t fvel){ actuator_buf[0] = LOC_ACTUATOR_ADDR; actuator_buf[1] = FDIR;
actuator_buf[2] = fvel;
actuator_buf[3] = FDIR;
actuator_buf[4] = fvel;
I2C_send(LOC_ID_ROBOT, actuator_buf, actuator_blen); }

// Funció per a moure enrere el robot
void move_backward(uint8_t bvel){ actuator_buf[0] = LOC_ACTUATOR_ADDR; actuator_buf[1] = BDIR;
actuator_buf[2] = bvel;
actuator_buf[3] = BDIR;
actuator_buf[4] = bvel;
I2C_send(LOC_ID_ROBOT, actuator_buf, actuator_blen); }

// Funció per a girar cap a l'esquerra endavant
void fleft(uint8_t fleft_vel){
actuator_buf[0] = LOC_ACTUATOR_ADDR; actuator_buf[1] = FDIR;
actuator_buf[2] = STOP_WHEEL;
actuator_buf[3] = FDIR;
actuator_buf[4] = fleft_vel;
I2C_send(LOC_ID_ROBOT, actuator_buf, actuator_blen); }

// Funció per a girar cap a l'esquerra enrere
void bleft(uint8_t bleft_vel){ actuator_buf[0] = LOC_ACTUATOR_ADDR; actuator_buf[1] = FDIR;
actuator_buf[2] = STOP_WHEEL;

Curs 2024-2025
Informe desenvolupament del software del robot | Aidar Iglesias/David García Pérez

actuator_buf[3] = BDIR;
actuator_buf[4] = bleft_vel;
I2C_send(LOC_ID_ROBOT, actuator_buf, actuator_blen); }

// Funció per a rotar en sentit antihorari
void left_rot(uint8_t lrot_vel){ actuator_buf[0] = LOC_ACTUATOR_ADDR; actuator_buf[1] = BDIR;
actuator_buf[2] = lrot_vel;
actuator_buf[3] = FDIR;
actuator_buf[4] = lrot_vel;
I2C_send(LOC_ID_ROBOT, actuator_buf, actuator_blen); }

// Funció per a girar cap a la dreta endavant
void fright(uint8_t fright_vel){ actuator_buf[0] = LOC_ACTUATOR_ADDR; actuator_buf[1] = FDIR;
actuator_buf[2] = fright_vel;
actuator_buf[3] = FDIR;
actuator_buf[4] = STOP_WHEEL; I2C_send(LOC_ID_ROBOT, actuator_buf, actuator_blen); }

// Funció per a girar cap a la dreta enrere
void bright(uint8_t bright_vel){ actuator_buf[0] = LOC_ACTUATOR_ADDR; actuator_buf[1] = BDIR;
actuator_buf[2] = bright_vel;
actuator_buf[3] = FDIR;
actuator_buf[4] = STOP_WHEEL; I2C_send(LOC_ID_ROBOT, actuator_buf, actuator_blen); }

// Funció per a rotar en sentit horari
void right_rot(uint8_t rrot_vel){ actuator_buf[0] = LOC_ACTUATOR_ADDR; actuator_buf[1] = FDIR;
actuator_buf[2] = rrot_vel;
actuator_buf[3] = BDIR;
actuator_buf[4] = rrot_vel;
I2C_send(LOC_ID_ROBOT, actuator_buf, actuator_blen);

Curs 2024-2025
Informe desenvolupament del software del robot | Aidar Iglesias/David García Pérez

}
/*********************************************************************** *************/

## LINETRACKING

/*
* linetracking.c
*
* Microcontroladors i Sistemes Empotrats * Curs 2024-25
* Universitat de Barcelona
*
* Autors: David Garcia, Aidar Iglesias */

/********************************* LLIBRERIES ***************************************/ #include <msp430fr2355.h>
#include <stdint.h>

#include "timers.h"

#include "LCD_display.h"

#include "actuadors.h"

#include "delay_ms.h"

#include "i2c_master.h"

/*********************************************************************** *************/

/******************************* VARIABLES DE CONTROL *******************************/
#define LOC_ID_ROBOT 0x10 | // Adreça I2C del robot

#define LINE_TRACK_ADDR 0x1D | // Adreça del controlador del modul de

seguiment de linia
#define WAIT_10MS 10 | // Delay de 10ms entre la transmisio i

la rececpcio del line-track
uint8_t linetrack_reg[6]; | // Variable que emmagatzema els bits
d'estat de cadascun dels fotodetectors /*********************************************************************** *************/

Curs 2024-2025
Informe desenvolupament del software del robot | Aidar Iglesias/David García Pérez

/****************** Funcio d'execucio del mode de seguiment de linia ****************/
/* La funcio de seguiment de linia 'linetrack' accepta dos arguments. El primer es
* el mode de funcionament, el format del qual ve donat per un nombre enter de 8 bits.
* El segon argument es la velocitat del robot durant l'etapa de seguiment de linia.
* No retorna cap dada (tipus void).
*
* La funcio esta dividida en dos fases: la fase de mesura i la de presa de decisio.
* Durant la fase de presa de mesura s'envia la comanda de mesura via I2C al contro-
* lador dels fotodetectors. Un cop feta la mesura, les dades d'aquesta es processen
* i es preparen per a la següent fase. Durant la fase de presa de decisio s'envien
* comandes d'operacio als actuadors del robot en funcio del valor dels fotodetectors.
*
* La funcio te dos modes principals de funcionament: seguiment de linia i seguiment de
* paret. En el mode de seguiment de linia, el robot tractara de seguir la linia amb
* la roda passiva davantera, si mes no mantenir la linia entre les dues rodes actives.
* En el mode de seguiment de paret, el robot avançara fins que es trobi una paret, cas
* en el qual rotara cap a la dreta fins que detecti que no col·lisiona, aleshores
* avançara mantenint'se al marge d'aquesta.
*
* Els punts febles del robot son els camins sense sortida (tots els fotodetectors
* detecten una col·lisio imminent) i que en el mode de seguiment de paret, el robot
* evita la col·lisio, pero no mante una distancia constant amb la paret.
*/
void linetrack(uint8_t mode, uint8_t linetrack_vel) {

Curs 2024-2025
Informe desenvolupament del software del robot | Aidar Iglesias/David García Pérez

/********************** Fase de mesura dels fotodetectors ***********************/
// Inicialitzar els buffers de transmisio i recepcio
uint8_t tx_buf[1] = {LINE_TRACK_ADDR}; // Byte a enviar per activar el sensor
uint8_t rx_buf[1] = {0x00}; | // Byte de recepció
inicialitzat a 0
uint8_t tx_buf_len = sizeof(tx_buf); // Longitud del buffer de transmissio
uint8_t rx_buf_len = sizeof(rx_buf); // Longitud del buffer de recepcio

// Enviar la peticio de mesura al registre del modul line-track I2C_send(LOC_ID_ROBOT, tx_buf, tx_buf_len); delay_ms(WAIT_10MS);

// Rebre i desar la resposta
I2C_receive(LOC_ID_ROBOT, rx_buf, rx_buf_len);
linetrack_reg[0] = rx_buf[0] & ((uint8_t)BIT0); | // Extraiem i
desem els bits del registre
linetrack_reg[1] = (rx_buf[0] & ((uint8_t)BIT1)) >> 1; // dels fotodetectors mitjançant una mascara
linetrack_reg[2] = (rx_buf[0] & ((uint8_t)BIT2)) >> 2; // de bit i desplaçaments
linetrack_reg[3] = (rx_buf[0] & ((uint8_t)BIT3)) >> 3; linetrack_reg[4] = (rx_buf[0] & ((uint8_t)BIT4)) >> 4; linetrack_reg[5] = (rx_buf[0] & ((uint8_t)BIT5)) >> 5;

/*********************************************************************** *********/

/************************** Fase de presa de decisio ****************************/
switch(mode){

case 0: // Mode de funcionament: seguiment de linia (LINE_TRACK_MODE)
if(linetrack_reg[0]){
/* excrusio excessiva cap a la dreta --> rotar en sentit antihorari */
delay_ms(5);
left_rot(linetrack_vel);

Curs 2024-2025
Informe desenvolupament del software del robot | Aidar Iglesias/David García Pérez

delay_ms(5);
} else if(linetrack_reg[5]){
/* excursio excessiva cap a l'esquerra --> rotar en sentit horari */
delay_ms(5);
right_rot(linetrack_vel);
delay_ms(5);
} else if(linetrack_reg[1] | linetrack_reg[2]){
/* s'ha detectat limit esquerre de la linia --> girar cap a l'esquerra */
delay_ms(5);
fleft(linetrack_vel);
delay_ms(5);
} else if(linetrack_reg[3] | linetrack_reg[4]){
/* s'ha detectat limit dret de la linia --> girar cap a la dreta */
delay_ms(5);
bright(linetrack_vel);
delay_ms(5);
} else{
/* ens trobem dintre dels limits --> avançar */ delay_ms(5);
move_forward(linetrack_vel);
delay_ms(5);
}
break;

case 1: // Mode de funcionament seguiment de paret (WALL_FOLLOWER_MODE)
if(linetrack_reg[5] & linetrack_reg[4] & linetrack_reg[3] & linetrack_reg[2] & linetrack_reg[1] & linetrack_reg[0]){ /* s'ha arribat a un cami sense sortida --> aturem el robot*/
delay_ms(5);
stop();
delay_ms(5);
} else if(linetrack_reg[4] & linetrack_reg[3] & linetrack_reg[2] & linetrack_reg[1]){
/* s'ha arribat a una paret frontal --> aturem el robot*/ delay_ms(5);
stop();
delay_ms(5);
right_rot(linetrack_vel);

Curs 2024-2025
Informe desenvolupament del software del robot | Aidar Iglesias/David García Pérez

delay_ms(500);
stop();
delay_ms(5);
} else if(linetrack_reg[1] & linetrack_reg[0]){
/* s'ha detectat una cantonada esquerra --> rota en sentit horari*/
delay_ms(5);
right_rot(linetrack_vel);
delay_ms(5);
} else if(linetrack_reg[5] & linetrack_reg[4]){
/* s'ha detectat una cantonada dreta --> rota en sentit antihorari*/
delay_ms(5);
left_rot(linetrack_vel);
delay_ms(5);
} else if(linetrack_reg[0]){
/* s'ha detectat una paret lateral a l'esquerra --> gira cap a la dreta */
delay_ms(5);
fright(linetrack_vel);
delay_ms(5);
} else if(linetrack_reg[5]){
/* s'ha detectat una paret lateral a la dreta --> gira cap a l'esquerra */
delay_ms(5);
fleft(linetrack_vel);
delay_ms(5);
} else{
/* en qualsevol altre cas --> avança */ delay_ms(5);
move_forward(0.8*linetrack_vel); delay_ms(5);
}
break;
}

/*********************************************************************** *********/
}
/*********************************************************************** *************/

Curs 2024-2025
Informe desenvolupament del software del robot | Aidar Iglesias/David García Pérez

## MAIN

/*
* main.c
*
* Microcontroladors i Sistemes Empotrats * Curs 2024-25
* Universitat de Barcelona
*
* Autors: David Garcia, Aidar Iglesias */

/********************************* LLIBRERIES ***********************************/
// Llibreries estandard de C i del microcontrolador #include <msp430fr2355.h>
#include <stdint.h>

#include <stdio.h>

// Fitxers de capçalera
#include "timers.h"

#include "delay_ms.h"

#include "i2c_master.h"

#include "LEDs.h"

#include "LCD_display.h"

#include "actuadors.h"

#include "linetracking.h"

/*********************************************************************** *********/

/***************************** Variables globals ********************************/
/* En aquest apartat es defineixen tant les variables globals com les macros emprades
* en els diferents moduls del programa
*/
// Variables delay
#define WAIT_1MS 1 | // Espera d'un mil·lisegon

#define WAIT_100MS 100 | // Espera de cent mil·lisegons

#define WAIT_HALF_SEC 500 | // Espera de mig segon

#define WAIT_1S 1000 | // Espera d'un segon

#define WAIT_2S 2000 | // Espera de dos segons

Curs 2024-2025
Informe desenvolupament del software del robot | Aidar Iglesias/David García Pérez

// ID del robot com a esclau
#define GLOB_ID_ROBOT 0x10 | // Identificador del robot

// LCD display robot
#define GLOB_LCD_ADDR 0x3E | // Adreça del display LCD

#define LCD_TX_DELAY 10 | // Espera entre missatges enviats al LCD

// Actuadors
#define GLOB_ACTUATOR_ADDR 0x00 // Adreça global del controlador d'actuadors

#define VEL 40 | // Velocitat inicial dels actuadors

// Line-Track
#define LINETRACK_VEL 40 | // Velocitat del robot en mode

line-track
/* Creem un bloc condicional a nivell de compilador per escollir el mode de funcionament
* del modul line-track amb les macros #ifndef, #define i #endif
*/
#define LINE_TRACK_MODE 0 | // Mode de funcionament: seguiment de

linia centrada
#ifndef LINE_TRACK_MODE

#define WALL_FOLLOWER_MODE 1 // Mode de funcionament: seguiment de paret

#endif

/*********************************************************************** *********/

/************************ Funcio inicialitzacio de rellotges ********************/
void init_clock(void)
{
FRCTL0 = FRCTLPW | NWAITS_1;
P2SEL1 |= BIT6 | BIT7; | // P2.6~P2.7: crystal pins
do
{
CSCTL7 &= ~(XT1OFFG | DCOFFG); // Clear XT1 and DCO fault flag
SFRIFG1 &= ~OFIFG;
}while (SFRIFG1 & OFIFG); | // Test oscillator fault flag

Curs 2024-2025
Informe desenvolupament del software del robot | Aidar Iglesias/David García Pérez
__bis_SR_register(SCG0); | // disable FLL
CSCTL3 |= SELREF__XT1CLK; | // Set XT1 as FLL reference
source
//CSCTL1 = DCOFTRIMEN_1 | DCOFTRIM0 | DCOFTRIM1 | DCORSEL_5; //
DCOFTRIM=5, DCO Range = 16MHz**
CSCTL1 = DCORSEL_5; | // DCOFTRIM=5, DCO Range = 16MHz
CSCTL2 = FLLD_0 + 487; | // DCOCLKDIV = 16MHz
__delay_cycles(3);
__bic_SR_register(SCG0); | // enable FLL
//Software_Trim(); | // Software Trim to get the best
DCOFTRIM value**
CSCTL4 = SELMS__DCOCLKDIV | SELA__XT1CLK; // set XT1 (~32768Hz) as
ACLK source, ACLK = 32768Hz
// default DCOCLKDIV as
MCLK and SMCLK source
// P1DIR |= BIT0 | BIT1; | // set SMCLK, ACLK pin as output
// P1SEL1 |= BIT0 | BIT1; | // set SMCLK and ACLK pin as
second function
PM5CTL0 &= ~LOCKLPM5; | // Disable the GPIO power-on
default high-impedance mode
// to activate previously
configured port settings
}
/*********************************************************************** *********/

/*********** Funcio inicialitzacio LED P1.0 de la placa Launchpad ***************/
void init_LED_MSP(){
P1DIR |= BIT0; | // LED P1.0 com a sortida
P1SEL0 &= ~(BIT0); // Funcio principal del
P1SEL1 &= ~(BIT0); // pin com a GPIO
}
/*********************************************************************** *********/

/*********** Funcio inicialitzacio pin P2.0 de la placa Launchpad ***************/
void init_Port2IO(void){

Curs 2024-2025
Informe desenvolupament del software del robot | Aidar Iglesias/David García Pérez
P2DIR |= BIT0; | // P2.0 com a sortida
P2SEL0 &= ~(BIT0); // Funcio principal del
P2SEL1 &= ~(BIT0); // pin com a GPIO
}
/*********************************************************************** *********/

/************************* BEGIN MAIN PROGRAM ***********************************/
void main(void)
{
WDTCTL = WDTPW | WDTHOLD; // stop watchdog timer

/******************** Habilitar interrupcions globals ***********************/
__enable_interrupt();

/*********************************************************************** *****/

/************************ Inicialitzacio de funcions ************************/
// Inicialitzacio de rellotges
init_clock();
// Inicialitzacio de l'I2C
i2c_init();
// Inicialitzacio del LED P1.0 de la placa (nomes al Launchpad) init_LED_MSP();
// Inicialitzacio del pin P2.0 de la placa (nomes al Launchpad) init_Port2IO();
// Inicialitzacio del TimerB3
init_TimerB3();
// Inicialitzacio del display LCD
init_LCD();

/*********************************************************************** *****/

/****************** Comprovacio de la funcio delay_ms()**********************/
// Comprovar la funcio delay_ms()

Curs 2024-2025
Informe desenvolupament del software del robot | Aidar Iglesias/David García Pérez
P1OUT |= BIT0; | // Encenem el LED vermell P1.0
P2OUT |= BIT0; | // Posem a nivell logic alt el pin 2.0
delay_ms(WAIT_1S); // Esperem un segon
P1OUT &= ~(BIT0); | // Apaguem el LED vermell P1.0
P2OUT &= ~(BIT0); | // Posem a nivell logic baix el pin 2.0

/*********************************************************************** *****/

/********************* Control de LEDs RGB del robot ************************/
// Escriptura als LEDs RGB frontals del robot
red_LEDs(); | // Encendre els LEDs de color vermell
delay_ms(WAIT_HALF_SEC); | // Esperar mig segon
green_LEDs(); | // Encendre els LEDs de color verd
delay_ms(WAIT_HALF_SEC); | // Esperar mig segon
yellow_LEDs(); | // Encendre els LEDs de color groc
delay_ms(WAIT_HALF_SEC); | // Esperar mig segon
blue_LEDs(); | // Encendre els LEDs de color blau
delay_ms(WAIT_HALF_SEC); | // Esperar mig segon
magenta_LEDs(); | // Encendre els LEDs de color magenta
delay_ms(WAIT_HALF_SEC); | // Esperar mig segon
cyan_LEDs(); | // Encendre els LEDs de color cyan
delay_ms(WAIT_HALF_SEC); | // Esperar mig segon
white_LEDs(); | // Encendre els LEDs de color blanc
delay_ms(WAIT_HALF_SEC); | // Esperar mig segon
cule_LEDs(); | // Encendre els LEDs de color FC
Blaugrana
delay_ms(WAIT_HALF_SEC); | // Esperar mig segon
merengue_LEDs(); | // Encendre els LEDs de color Real
Madrid CF
delay_ms(WAIT_HALF_SEC); | // Esperar mig segon
perico_LEDs(); | // Encendre els LEDs de color RCD
Espanyol
delay_ms(WAIT_HALF_SEC); | // Esperar mig segon
gironi_LEDs(); | // Encendre els LEDs de color Girona
FC
delay_ms(WAIT_HALF_SEC); | // Esperar mig segon
reset_LEDs(); | // Apagar els LEDs
delay_ms(WAIT_HALF_SEC); | // Esperar mig segon

/***********************************************************************

Curs 2024-2025
Informe desenvolupament del software del robot | Aidar Iglesias/David García Pérez

*****/

/*********************** Comunicacio amb LCD display ************************/
uint8_t msg[12]; | // Array on es desa el
missatge a transmetre
/* Desem cadascun dels caracters del contingut del missatge en una variable de
* tipus array mitjançant la funció de C sprintf() i desem la mida d'aquest */
uint8_t msg_len = sprintf(msg, "@Hello World"); delay_ms(LCD_TX_DELAY); // Esperem 10ms
I2C_send(GLOB_LCD_ADDR, msg, msg_len); // Enviem el missatge per I2C al LCD
delay_ms(WAIT_2S); | // Esperem 2s
LCD_clear(); | // Esborrem el contingut en pantalla
delay_ms(LCD_TX_DELAY); // Esperem 10ms
LCD_send(); | // Enviem el missatge "INFORME SOFTWARE
MISE" al LCD

/*********************************************************************** *****/

/************************* Control dels actuadors ***************************/
move_forward(VEL); // Habilitar els actuadors per avançar delay_ms(WAIT_1S); // Esperar un segon
fleft(VEL); | // Habilitar els actuadors per girar cap a
l'esquerra endavant
delay_ms(WAIT_1S); // Esperar un segon
fright(VEL); | // Habilitar els actuadors per girar cap a la
dreta endavant
delay_ms(WAIT_1S); // Esperar un segon
stop(); | // Deshabilitar els actuadors per aturar el
robot
delay_ms(WAIT_1S); // Esperar un segon
move_backward(VEL); // Habilitar els actuadors per retrocedir delay_ms(WAIT_1S); // Esperar un segon
bleft(VEL); | // Habilitar els actuadors per girar cap a
l'esquerra enrere
delay_ms(WAIT_1S); // Esperar un segon

Curs 2024-2025
Informe desenvolupament del software del robot | Aidar Iglesias/David García Pérez
bright(VEL); | // Habilitar els actuadors per girar cap a la
dreta enrere
delay_ms(WAIT_1S); // Esperar un segon
stop(); | // Deshabilitar els actuadors per aturar el
robot
delay_ms(WAIT_1S); // Esperar un segon
left_rot(VEL); | // Habilitar els actuadors per rotar en sentit
antihorari
delay_ms(WAIT_1S); // Esperar un segon
right_rot(VEL); // Habilitar els actuadors per rotar en sentit horari
delay_ms(WAIT_1S); // Esperar un segon
stop(); | // Deshabilitar els actuadors per aturar el
robot

/*********************************************************************** *****/

while(1){ // Bucle infinit per al main
// Codi per a la comprovacio del delay a traves de l'oscil·loscopi
P2OUT |= BIT0; | // Posem a nivell logic alt el pin 2.0
delay_ms(WAIT_100MS); // Esperem un segon
P2OUT &= ~(BIT0); // Posem a nivell logic baix el pin 2.0 delay_ms(WAIT_100MS); // Esperem un segon

// Codi del Line-Track
delay_ms(50);
/* En funcio de quin mode de funcionament del modul de line-track s'ha escollit
* al principi, s'executa la funcio amb el mode corresponent */
#ifdef LINE_TRACK_MODE

linetrack(LINE_TRACK_MODE, LINETRACK_VEL);
#else

linetrack(WALL_FOLLOWER_MODE, LINETRACK_VEL); #endif
}
}
/*********************************************************************** *********/

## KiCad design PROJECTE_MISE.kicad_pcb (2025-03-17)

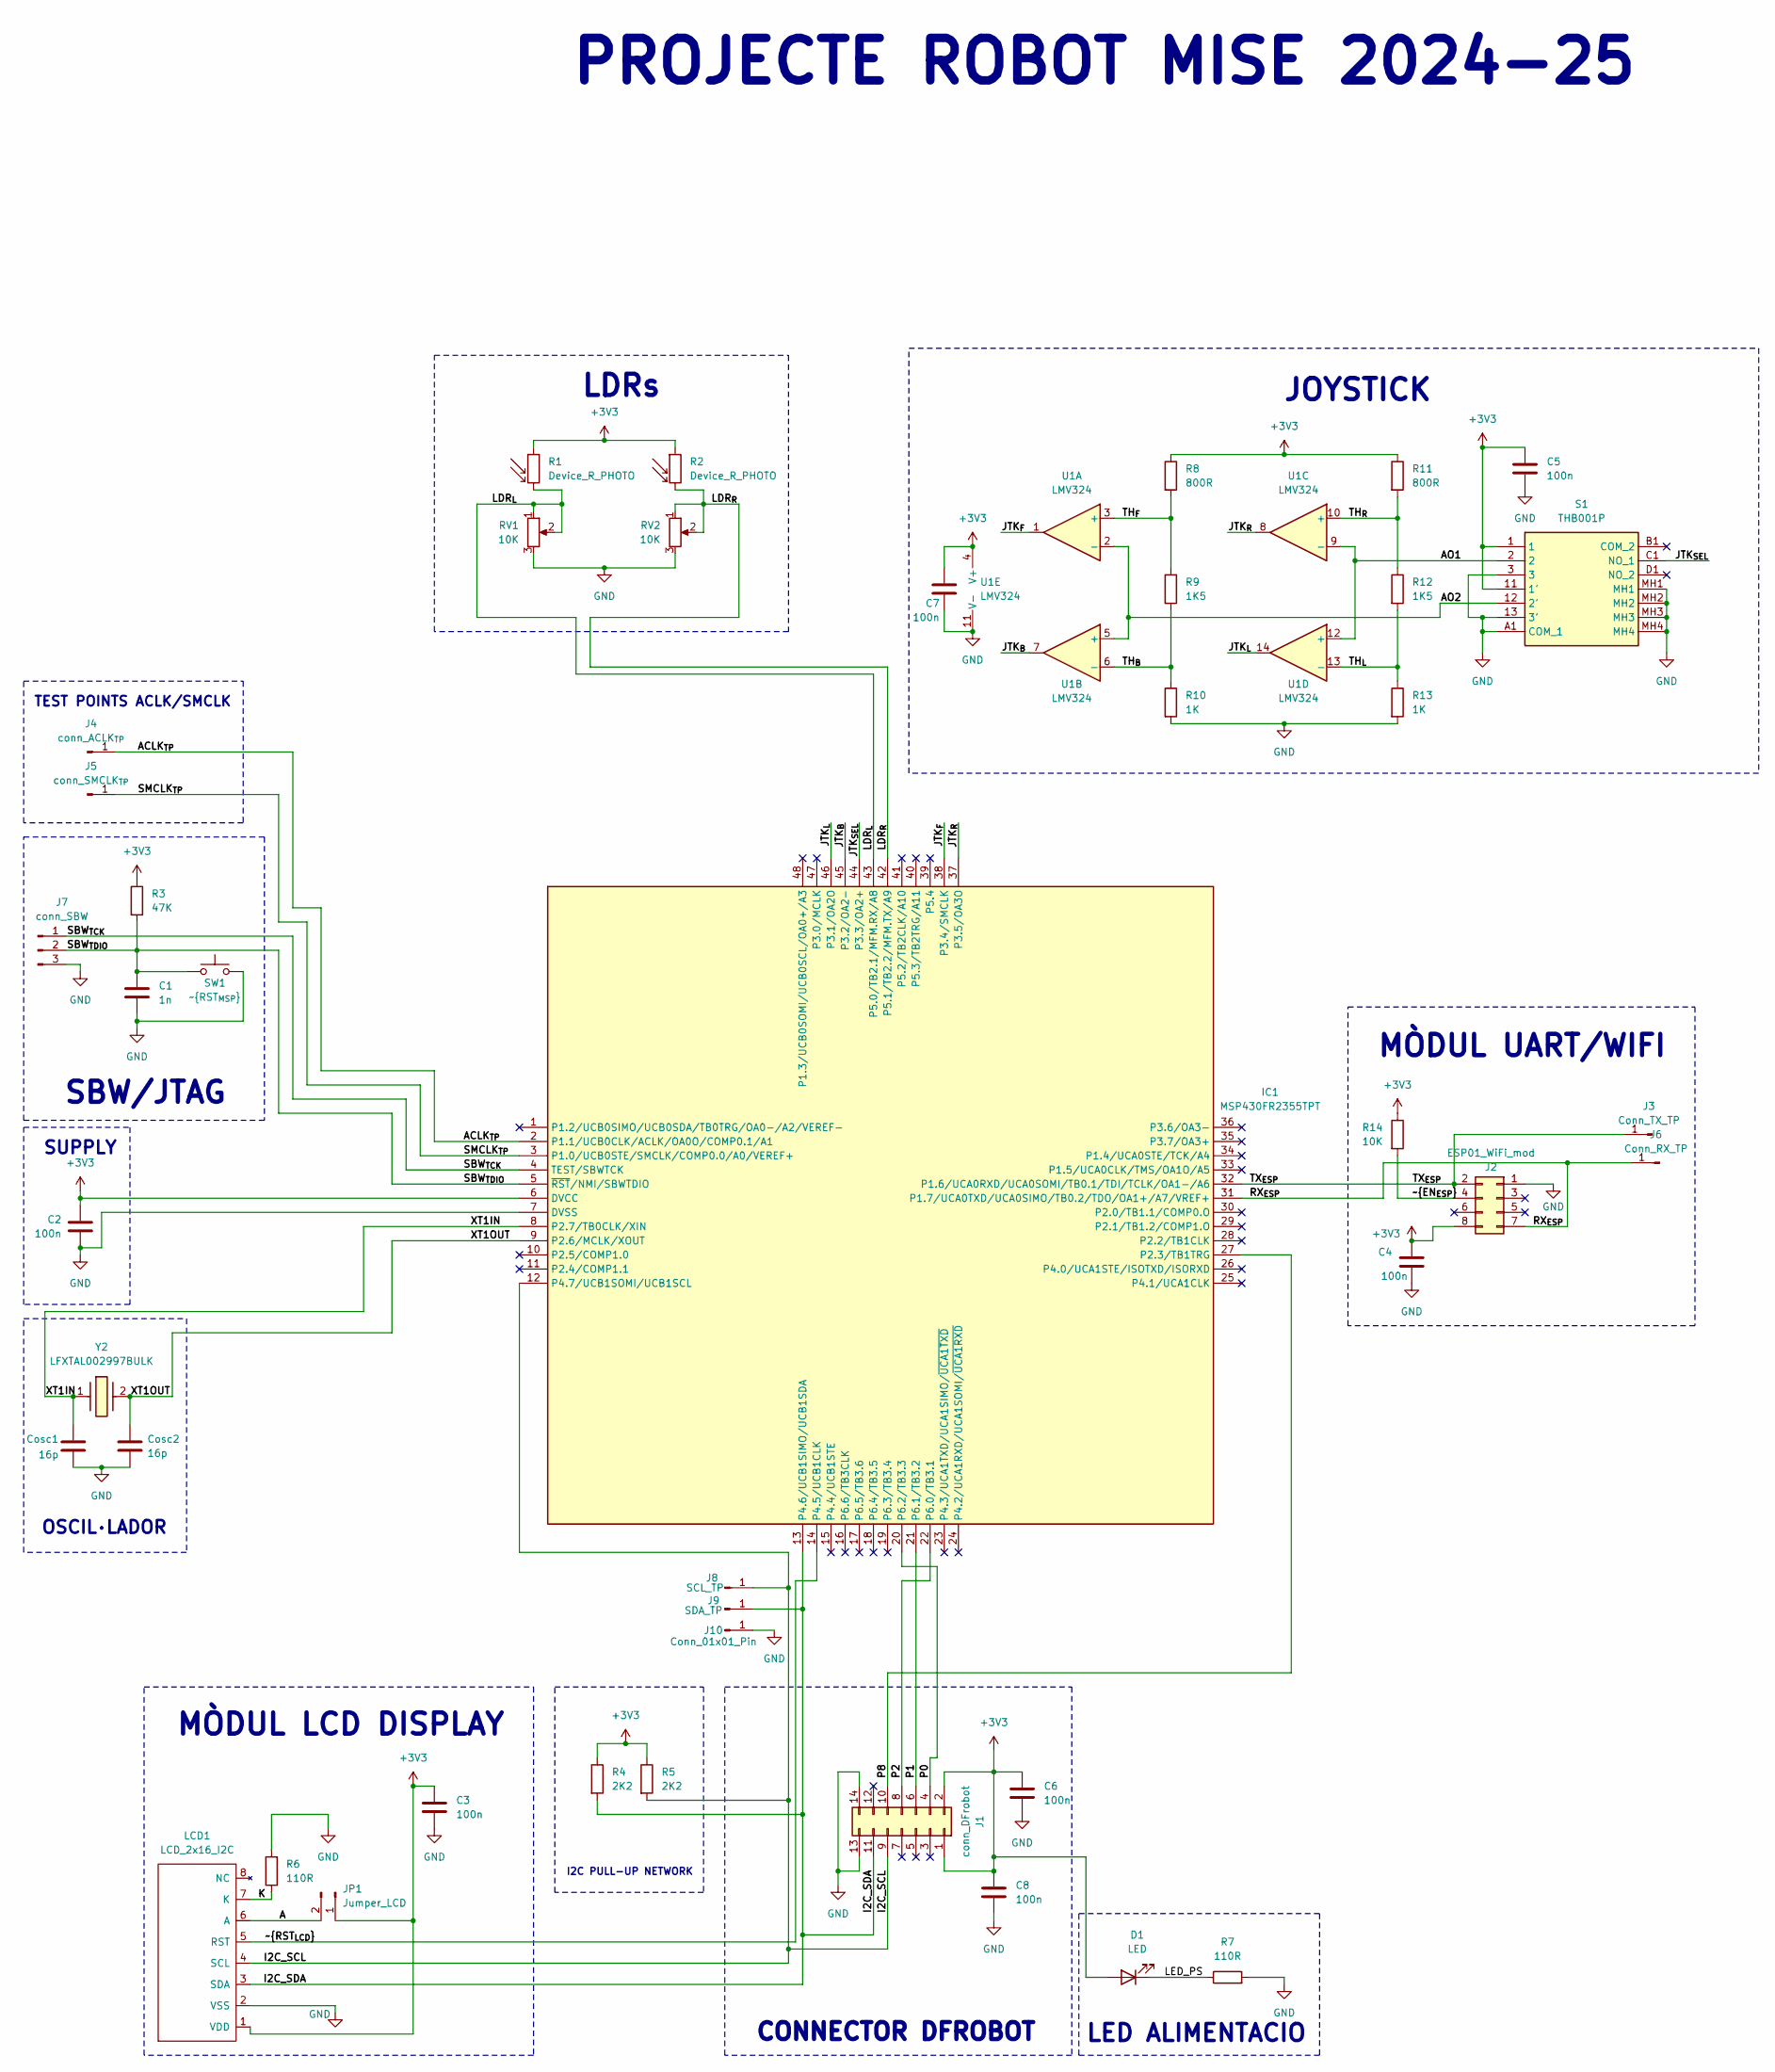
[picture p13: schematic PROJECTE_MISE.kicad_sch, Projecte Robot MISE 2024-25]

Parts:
C1: 1n; C_0805_2012Metric
C2, C3, C4, C5, C6, C7, C8: 100n; C_0805_2012Metric
Cosc1, Cosc2: 16p; C_0805_2012Metric
D1: LED; LED_0805_2012Metric
IC1: MSP430FR2355TPT; QFP50P900X900X160-48N; Manufacturer_Part_Number MSP430FR2355TPT; Mouser Part Number 595-MSP430FR2355TPT
J1: conn_DFrobot
J2: ESP01_WiFi_mod; PinSocket_2x04_P2.54mm_Vertical
J3: Conn_TX_TP; PinHeader_1x01_P2.00mm_Vertical
J4: conn_ACLK_{TP}; PinHeader_1x01_P2.00mm_Vertical
J5: conn_SMCLK_{TP}; PinHeader_1x01_P2.00mm_Vertical
J6: Conn_RX_TP; PinHeader_1x01_P2.00mm_Vertical
J7: conn_SBW; PinHeader_1x03_P2.54mm_Vertical
J8: SCL_TP; PinHeader_1x01_P2.00mm_Vertical
J9: SDA_TP; PinHeader_1x01_P2.00mm_Vertical
J10: Conn_01x01_Pin; PinHeader_1x01_P2.00mm_Vertical
JP1: Jumper_LCD; PinHeader_2x01_P2.00mm_Vertical
LCD1: LCD_2x16_I2C; LCD_2x16_I2C(Midas)
R1, R2: Device_R_PHOTO; LDR
R3: 47K; R_0805_2012Metric
R4, R5: 2K2; R_0805_2012Metric
R6, R7: 110R; R_0805_2012Metric
R8, R11: 800R; R_0805_2012Metric
R9, R12: 1K5; R_0805_2012Metric
R10, R13: 1K; R_0805_2012Metric
R14: 10K; R_0805_2012Metric
RV1, RV2: 10K; Trimmer_MiSE
S1: THB001P; Manufacturer_Part_Number THB001P; Mouser Part Number 611-THB001P
SW1: ~{RST_{MSP}}; SW_PUSH_6mm
U1: LMV324; SOIC-14_3.9x8.7mm_P1.27mm
Y2: LFXTAL002997BULK; LFXTAL002997Bulk_modificat; Mouser Part Number 449-LFXTAL002997BULK

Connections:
+3V3: C2.1, C3.1, C4.1, C5.1, C6.1, C7.1, C8.1, D1.2 (A), IC1.6 (DVCC), J1.1, J1.2, J2.8, JP1.1, LCD1.1 (VDD), R1.1, R2.1, R3.1, R4.1, R5.1, R8.1, R11.1, R14.1, S1.1, S1.11 (1'), U1.4 (V+)
/A: JP1.2, LCD1.6 (A)
/ACLK_{TP}: IC1.2 (P1.1/UCB0CLK/ACLK/OA0O/COMP0.1/A1), J4.1
/AO1: S1.2, U1.9 (-), U1.12 (+)
/AO2: S1.12 (2'), U1.2 (-), U1.5 (+)
/I2C_SCL: IC1.12 (P4.7/UCB1SOMI/UCB1SCL), J1.9, J8.1, LCD1.4 (SCL), R5.2
/I2C_SDA: IC1.13 (P4.6/UCB1SIMO/UCB1SDA), J1.11, J9.1, LCD1.3 (SDA), R4.2
/JTK_{B}: IC1.45 (P3.2/OA2-), U1.7
/JTK_{F}: IC1.38 (P3.4/SMCLK), U1.1
/JTK_{L}: IC1.46 (P3.1/OA2O), U1.14
/JTK_{R}: IC1.37 (P3.5/OA3O), U1.8
/JTK_{SEL}: IC1.44 (P3.3/OA2+), S1.C1 (NO_1)
/K: LCD1.7 (K), R6.1
/LDR_{L}: IC1.43 (P5.0/TB2.1/MFM.RX/A8), R1.2, RV1.1, RV1.2
/LDR_{R}: IC1.42 (P5.1/TB2.2/MFM.TX/A9), R2.2, RV2.1, RV2.2
/LED_PS: D1.1 (K), R7.1
/P0: IC1.20 (P6.2/TB3.3), J1.4
/P1: IC1.21 (P6.1/TB3.2), J1.6
/P2: IC1.22 (P6.0/TB3.1), J1.8
/P8: IC1.27 (P2.3/TB1TRG), J1.10
/RX_{ESP}: IC1.31 (P1.7/UCA0TXD/UCA0SIMO/TB0.2/TDO/OA1+/A7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), J2.7, J6.1
/SBW_{TCK}: IC1.4 (TEST/SBWTCK), J7.1
/SBW_{TDIO}: C1.1, IC1.5 (~RST/NMI/SBWTDIO), J7.2, R3.2, SW1.1
/SMCLK_{TP}: IC1.3 (P1.0/UCB0STE/SMCLK/COMP0.0/A0/VEREF+), J5.1
/TH_{B}: R9.2, R10.1, U1.6 (-)
/TH_{F}: R8.2, R9.1, U1.3 (+)
/TH_{L}: R12.2, R13.1, U1.13 (-)
/TH_{R}: R11.2, R12.1, U1.10 (+)
/TX_{ESP}: IC1.32 (P1.6/UCA0RXD/UCA0SOMI/TB0.1/TDI/TCLK/OA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), J2.2, J3.1
/XT1IN: Cosc1.1, IC1.8 (P2.7/TB0CLK/XIN), Y2.1
/XT1OUT: Cosc2.1, IC1.9 (P2.6/MCLK/XOUT), Y2.2
/~EN_{ESP}: J2.4, R14.2
/~RST_{LCD}: IC1.14 (P4.5/UCB1CLK), LCD1.5 (RST)
GND: C1.2, C2.2, C3.2, C4.2, C5.2, C6.2, C7.2, C8.2, Cosc1.2, Cosc2.2, IC1.7 (DVSS), J1.13, J1.14, J2.1, J7.3, J10.1, LCD1.2 (VSS), R6.2, R7.2, R10.2, R13.2, RV1.3, RV2.3, S1.3, S1.13 (3'), S1.A1 (COM_1), S1.MH1, S1.MH2, S1.MH3, S1.MH4, SW1.2, U1.11 (V-)

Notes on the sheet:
OSCIL·LADOR
TEST POINTS ACLK/SMCLK
PROJECTE ROBOT MISE 2024-25
MÒDUL UART/WIFI
SUPPLY
I2C PULL-UP NETWORK
CONNECTOR DFROBOT
MÒDUL LCD DISPLAY
SBW/JTAG
LED ALIMENTACIO
LDRs
JOYSTICK

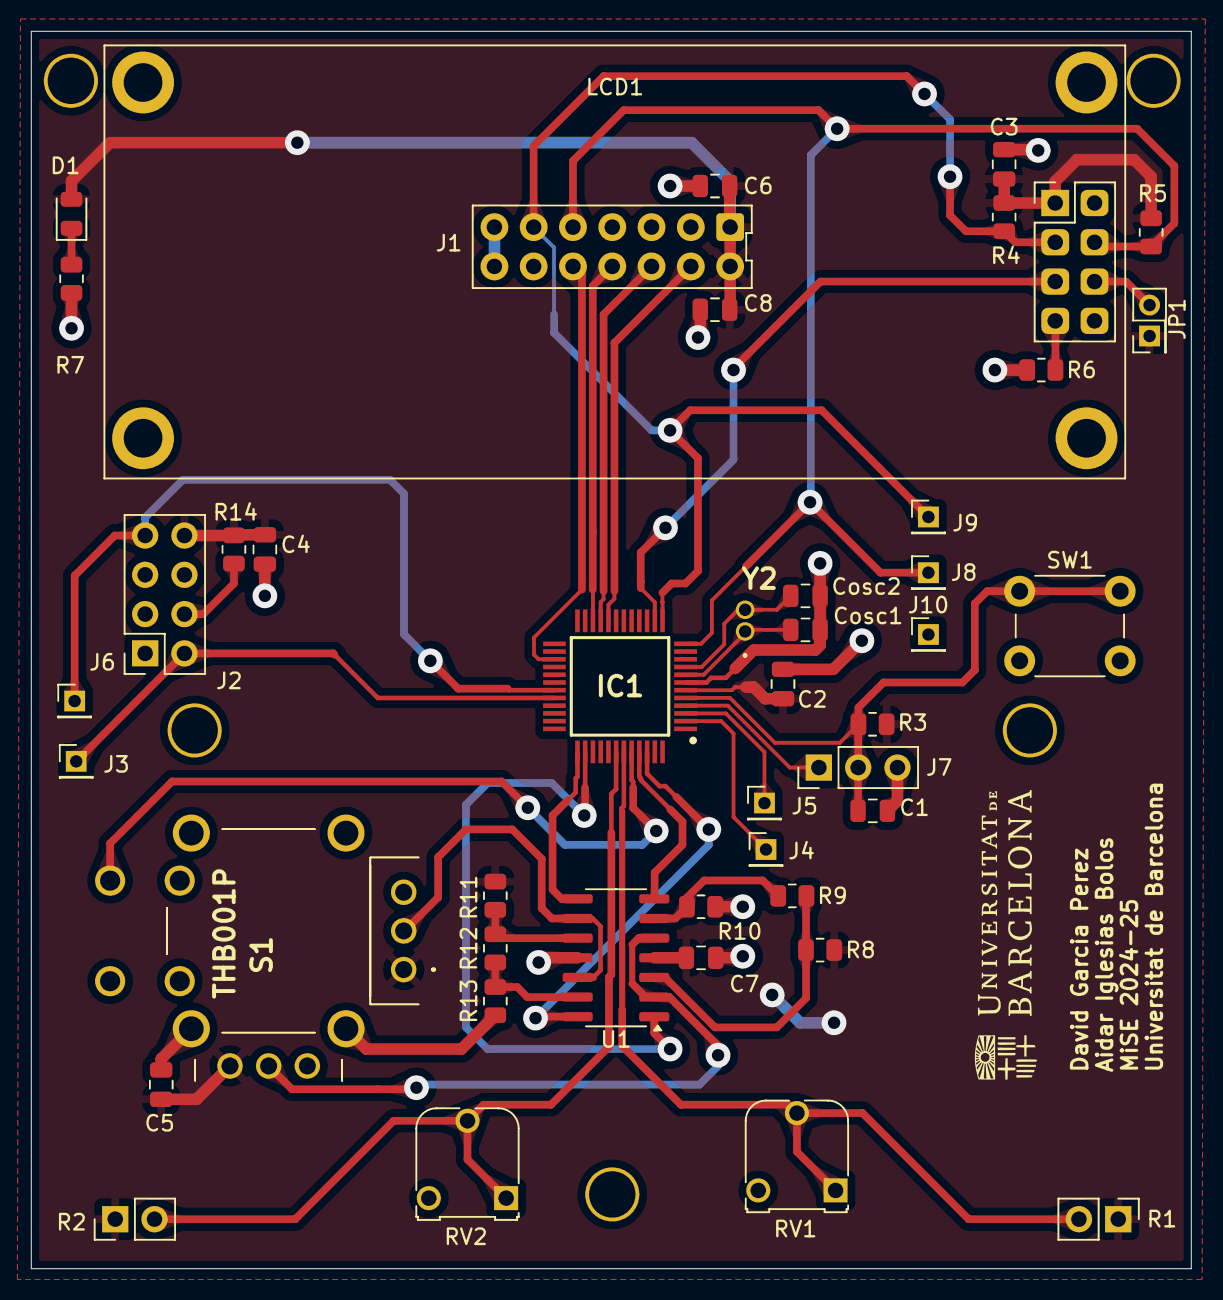
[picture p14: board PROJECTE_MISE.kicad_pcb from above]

Board: 2 copper layers, 75.0 x 80.0 mm, 44 parts (0 on the bottom side), 34 nets.

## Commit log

2025-02-27 added design files and gitignore
    [PROJECTE_MISE.kicad_pcb, PROJECTE_MISE.kicad_sch]
2025-02-27 rotate conn_DFRobot image
    [PROJECTE_MISE.kicad_sch]
2025-02-27 Revert "rotate conn_DFRobot image"
    This reverts commit 6e819256481b9d06e6faf2437fc47867e73514bb.
    [PROJECTE_MISE.kicad_sch]
2025-02-27 LDR image
    [PROJECTE_MISE.kicad_sch]
2025-02-27 modul wifi girat
    [PROJECTE_MISE.kicad_sch]
2025-02-28 updated wifi & crystal
    [PROJECTE_MISE.kicad_sch]
2025-02-28 first layout placement
    [PROJECTE_MISE.kicad_pcb]
2025-02-28 layout better
    [PROJECTE_MISE.kicad_pcb]
2025-03-04 placement i canvi esqu.
    [PROJECTE_MISE.kicad_pcb, PROJECTE_MISE.kicad_sch]
2025-03-07 layout conn_robot
    [PROJECTE_MISE.kicad_pcb, PROJECTE_MISE.kicad_sch]
2025-03-08 layout with LDRs and better conn
    [PROJECTE_MISE.kicad_pcb]
2025-03-08 layout ESP module and comparators
    [PROJECTE_MISE.kicad_pcb]
2025-03-08 algun canvi apart
    [PROJECTE_MISE.kicad_sch]
2025-03-09 layout new placement and nee changes
    [PROJECTE_MISE.kicad_pcb, PROJECTE_MISE.kicad_sch]
2025-03-09 update layout - routing
    [PROJECTE_MISE.kicad_pcb, PROJECTE_MISE.kicad_sch]
2025-03-10 layout finished but it has to be checked
    [PROJECTE_MISE.kicad_pcb, PROJECTE_MISE.kicad_sch]
2025-03-10 modificacions layout
    [PROJECTE_MISE.kicad_pcb, PROJECTE_MISE.kicad_sch]
2025-03-10 layout 0 errors 0 warnings
    [PROJECTE_MISE.kicad_pcb, PROJECTE_MISE.kicad_sch]
2025-03-11 layout finished 0 errors, 0 warnings and solved problems
    [PROJECTE_MISE.kicad_pcb, PROJECTE_MISE.kicad_sch]
2025-03-11 final layout + gerbers
    [PROJECTE_MISE-B_Cu.gbr, PROJECTE_MISE-B_Mask.gbr, PROJECTE_MISE-Edge_Cuts.gbr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]
2025-03-12 fixes layout + pending VCC LED, C ESP & redraw gerbers
    [PROJECTE_MISE.kicad_pcb, PROJECTE_MISE.kicad_sch]
2025-03-12 layout finished
    [PROJECTE_MISE.kicad_pcb, PROJECTE_MISE.kicad_sch]
2025-03-14 update R value LED_PS + update gerber files
    [PROJECTE_MISE-B_Cu.gbr, PROJECTE_MISE-B_Mask.gbr, PROJECTE_MISE-Edge_Cuts.gbr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]
2025-03-17 gerbers update and final version
    [PROJECTE_MISE-B_Cu.gbr, PROJECTE_MISE-B_Mask.gbr, PROJECTE_MISE-Edge_Cuts.gbr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]
